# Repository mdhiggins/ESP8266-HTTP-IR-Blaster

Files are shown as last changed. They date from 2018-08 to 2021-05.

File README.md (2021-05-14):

# IR Controller

ESP8266 Compatible IR Blaster that accepts HTTP commands for use with services like Amazon's Alexa

<a href="https://youtu.be/JysKXOdrOlM">Setup</a>

The purpose of this project was to create a Wi-Fi enabled IR blaster that could be controlled with Amazon Alexa
This was designed with the NodeMCU board but should be compatible with multiple ESP8266 variants

Includes a functional web portal for code capture, output monitoring, and device state tracking

Device gives real time LED feedback, can handle complex code sequences for multi-device home theater control, and full integration with Amazon Alexa via the smart home entertainment devices API and the `IR Controller` Alexa skill

Hardware
--------------
Fancy
Breadboard Build
Schematic

The hardware is based on the NodeMCU ESP8266 board and uses an infrared LED combined with the 2N2222 transistor for increased current and range. Values of the resistors seen in the schematic are variable and will depend on the specifications of your LED. If you're using the LED recommended below then a 1000 ohm resister to the 2N2222 transistor and a 10 ohm resistor to the LED itself are appropriate values, otherwise please use an LED resistance calculator. In total the parts come in around $10 so building a controller for each IR enabled device in your home is very feasible, and most components are cheaper in bulk

Shopping List:
- [ESP8266 NodeMCU Board](https://www.amazon.com/gp/product/B01IK9GEQG/)
- [IR Receiver](https://www.amazon.com/gp/product/B00EFOQEUM/)
- [Super bright IR Led](https://www.amazon.com/gp/product/B00ULB0U44/)
- [2N2222 Transistor](https://www.amazon.com/gp/product/B00R1M3DA4/)
- [Resistors](https://www.amazon.com/gp/product/B00YX75O5M/)

*These are just quick Amazon references. Parts can be purchased cheaper with longer shipping times from places like AliExpress*

Drivers
--------------
Install the NodeMCU drivers for your respective operating system if they are not autodetected

https://www.silabs.com/products/development-tools/software/usb-to-uart-bridge-vcp-drivers

Alexa Skill
--------------
The companion skill for the Amazon Alexa service is available [here](https://www.amazon.com/Michael-Higgins-IR-Controller/dp/B0762YYDS9) for US/CA/UK/IN/DE Alexa customers

Setup
--------------

If you use [PlatformIO](https://platformio.org/), you can clone the repository and run `platformio run -t upload` to
compile the library and upload it to a connected ESP8266-compatible board.

Otherwise, here are the building steps:

1. Install [Arduino IDE](https://www.arduino.cc/en/main/software)
2. Install [ESP8266 Arduino Core](https://github.com/esp8266/Arduino)
3. Install the following libraries from the Arduino IDE [Library Manager](https://www.arduino.cc/en/Guide/Libraries): `ESP8266WebServer` `ESP8266WiFi` `ArduinoJson` `Time` `IRremoteESP8266` as well as [`Cryptosuite`](https://github.com/jjssoftware/Cryptosuite) and the developer version of [`WiFiManager`] which is now on the IDE (version >= 2.0)
4. Load the `IRController.ino` blueprint from this repository
5. Upload blueprint to your ESP8266 (the .ino file). Monitor via serial at 115200 baud rate

After flashing, you can use the device like so:

1. Device will boot into WiFi access point mode initially with SSID `IR Controller Configuration`, IP address `192.168.4.1`. Connect to this and configure your access point settings using WiFi Manager. If your router supports mDNS/Bonjour you can now access your device on your local network via the hostname you specified (`http://hostname.local:port/`), otherwise via its local IP address (this IP address is displayed on the serial output)
2. Forward whichever port your ESP8266 web server is running on so that it can be accessed from outside your local network, this is critical since Alexa commands come from Amazon's servers, not locally
3. Download the IR Controller Alexa skill and start creating your devices. Each IR command will require a URL which can be saved. Choose whichever functionality you desire. Information on creating the URLs can be found below

Alexa Setup
---------------
1. Download the `IR Controller` skill from the Alexa skill store
2. Login with your Amazon account
3. Go to https://tehpsyc.pythonanywhere.com/
4. Login with the same Amazon account you used for the skill login
5. Create a new device by specifying the friendlyName, endpointId, and description
6. Add whichever functionality you want your device to have by scrolling through the options on the page
7. Save your new device
8. Run device discovery on your echo device by saying "Alexa, discover devices" or via https://alexa.amazon.com/
9. Verify that your new device was discovered online or in the Alexa app and enjoy!

Server Info
---------------


You may access basic device information at `http://xxx.xxx.xxx.xxx:port/` (webroot)

Capturing Codes
---------------
Your last scanned code can be accessed via web at `http://xxx.xxx.xxx.xxx:port/` or via serial monitoring over USB at 115200 baud. Most codes will be recognized and displayed in the format `A90:SONY:12`. Make a note of the code displayed in the serial output as you will need it for your maker channel URL. If your code is not recognized scroll down the JSON section of this read me.

NodeMCU PCU
---------------
@raptordemon has created a PCB that works great with this project. Use version 1.5
https://easyeda.com/raptordemon/ESP8266_IR_blaster-f8f224faba554bf3bb6ce0e32759fc23

Basic Output
--------------
For sending simple commands such as a single button press, or a repeating sequence of the same button press, use the logic below. This is unchanged from version 1.
Parameters
- `pass` - password required to execute IR command sending
- `code` - IR code such as `A90:SONY:12`
- `address` - (optional) Additional address data for NEC codes. Hex format
- `pulse` - (optional) Repeat a signal rapidly. Default `1`
- `pdelay` - (optional) Delay between pulses in milliseconds. Default `100`
- `repeat` - (optional) Number of times to send the signal. Default `1`. Useful for emulating multiple button presses for functions like large volume adjustments or sleep timer
- `rdelay` - (optional) Delay between repeats in milliseconds. Default `1000`
- `out` - (optional) Set which IRsend present to transmit over. Default `1`. Choose between `1-4`. Corresponding output pins set in the blueprint. Useful for a single ESP8266 that needs multiple LEDs pointed in different directions to trigger different devices

Example:
`http://xxx.xxx.xxx.xxx:port/msg?code=A90:SONY:12&pass=yourpass`

JSON Scripting
--------------
For more complicated sequences of buttons, such a multiple button presses or sending RAW IR commands or Pronto commands, you may do an HTTP POST with a JSON object that contains an array of commands which the receiver will parse and transmit. Payload must be a JSON array of JSON objects. Password should still be specified as the URL parameter `pass`.

Please note that Pronto codes are often given in a hexadecimal format and need to be prefixed with `0x` to indicate as such or they will be incorrectly transmitted.

Parameters
- `data` - IR code data, may be simple HEX code such as `"A90"` or an array of int values when transmitting a RAW sequence
- `type` - Type of signal transmitted. Example `"SONY"`, `"RAW"`, `"Delay"` or `"Roomba"` (and many others)
- `length` - (conditional) Bit length, example `12`. *Parameter does not need to be specified for RAW or Roomba signals*
- `pulse` - (optional) Repeat a signal rapidly. Default `1`
- `pdelay` - (optional) Delay between pulses in milliseconds. Default `100`
- `repeat` - (optional) Number of times to send the signal. Default `1`. *Useful for emulating multiple button presses for functions like large volume adjustments or sleep timer*
- `rdelay` - (optional) Delay between repeats in milliseconds. Default `1000`
- `khz` - (conditional) Transmission frequency in kilohertz. Default `38`. *Only required when transmitting RAW signal*
- `address` - (optional) Additional address data used for NEC codes. Hex format
- `out` - (optional) Set which IRsend present to transmit over. Default `1`. Choose between `1-4`. Corresponding output pins set in the blueprint. Useful for a single ESP8266 that needs multiple LEDs pointed in different directions to trigger different devices.

3 Button Sequence Example JSON
```
[
    {
        "type":"nec",
        "data":"FF827D",
        "length":32,
        "repeat":3,
        "rdelay":800
    },
    {
        "type":"nec",
        "data":"FFA25D",
        "length":32,
        "repeat":3,
        "rdelay":800
    },
    {
        "type":"nec",
        "data":"FF12ED",
        "length":32,
        "rdelay": 1000
    }
]
```

Raw Example
```
[
    {
    "type":"raw",
    "data":[2450,600, 1300,600, 700,550, 1300,600, 700,550, 1300,550, 700,550, 700,600, 1300,600, 700,550, 700,550, 700,550, 700],
    "khz":38,
    "pulse":3
    }
]
```

Pronto Example
```
[
    {
    type:"pronto",
    data: [0x0000, 0x0069, 0x0007, 0x0000, 0x032a, 0x010e, 0x005a, 0x010e, 0x005a, 0x005a, 0x0168, 0x005a, 0x005a, 0x010e, 0x005a, 0x00b4, 0x005a, 0x01c2]
    }
]
```

JSON as URL
--------------
To send the signal using the IFTTT Maker channel or the IR Controller smart home skill, simply take your JSON payload and remove spaces and line breaks so that entire packet is on a single line, then added it to the URL using the `plain` argument.

Sample URL using the same 3 button JSON sequence as above
```
http://xxx.xxx.xxx.xxx:port/json?pass=yourpass&plain=[{"type":"nec","data":"FF827D","length":32,"repeat":3,"rdelay":800},{"type":"nec","data":"FFA25D","length":32,"repeat":3,"rdelay":800},{"type":"nec","data":"FF12ED","length":32,"rdelay":1000}]
```

Security
---------------
Due to limitations imposed by the hardware in the ESP8266, there is not enough free memory to communicate over HTTPS/SSL. To protect your devices, during the WiFiManager setup process you can specify your Amazon user_id which will act as a secret key that allows SHA256 HMAC authentication to take place. Without this time sensitive signature no codes will be sent from the device. The user_id is a unique identifier tied to your account and my developer account, not shared across any other Amazon services. This unique ID can be found at the bottom of the tehpsyc.pythonanywhere.com page. The format is `amzn1.account.xxx`, **NOT your account email**. Enabling this feature will prevent sending commands via other means but greatly increases the security of the device. By default the option `bypassLocalAuth` is set to `true` which will allow requests made to the device coming from your local network (based on your local IP address and subnet) to be processed without the HMAC authentication.

To send commands over SSL you can use an intermediate service such as Smartthings (see below), use a reverse proxy with HTTPS support (which should work with the native Alexa skill) such a nginx, or handle everything on the local network and not use the functionality with Alexa.

This article provides some details on using nginx
https://jjssoftware.github.io/secure-your-esp8266/

Multiple LED Setup
--------------
If you are setting up your ESP8266 IR Controller to handle multiple devices, for example in a home theater setup, and the IR receivers are in different directions, you may use the `out` parameter to transmit codes with different LEDs which can be arranged to face different directions. Simply wire additional LEDs to a different GPIO pin on the ESP8266 in a similar fashion to the default transmitting pin and set the corresponding pin to the `irsend1-4` objects created at the top of the blueprint. For example if you wired an additional LED to the GPIO0 pin and you wanted to send a signal via that LED instead of the primary, you would modify irsend2 in the blueprint to `IRsend irsend2(0)` corresponding to the GPIO pin. Then when sending your signal via the url simply add `&out=2` and the signal will be sent via irsend2 instead of the primary irsend1.

Default mapping
- irsend1: GPIO4
- irsend2: GPIO5
- irsend3: GPIO12
- irsend4: GPIO13
- irrecv: GPIO14
- config: GPIO10

Force WiFi Reconfiguration
---------------
Set GPIO10 to ground to force a WiFi configuration reset, this will boot the device into WiFi host mode with an SSID of 'IR Controller Configuration' and IP of `192.168.4.1`

Device State Memory
---------------
By adding the `device` and `state` parameters to your URL or JSON object, the device will remember the last sent state of the device. This is useful since Alexa has separate on and off commands, and without knowing the device state will end up turning the TV on if an off command is issued

Example Turn On URL (if TV was already turned on, this command will do nothing):
`http://xxx.xxx.xxx.xxx:port/msg?code=A90:SONY:12&pass=yourpass&device=tv&state=1`

Example Turn Off URL (if TV was already turned off, this command will do nothing):
`http://xxx.xxx.xxx.xxx:port/msg?code=A90:SONY:12&pass=yourpass&device=tv&state=0`

Minimal Output
---------------
For configuring URLs to work with IFTTT or the IR Controller skill, or other automation services where the HTML output of the device will never be seen by a human, add `&simple=1` to the URL to simplify the data sent and speed up the response time

Example:
`http://xxx.xxx.xxx.xxx:port/msg?code=A90:SONY:12&pass=yourpass&simple=1`

IFTTT
--------------
If you are unable to use the Alexa skill for whatever reason, or you are using a competing voice control product or some other implementation, then IFTTT can also be used to execute commands using the Maker channel HTTP commands. Simply generate your URLs and save them in the Maker channel

Smartthings
--------------
For a great write up and instructional on how to integrate this device with Smartthings please visit http://thingsthataresmart.wiki/index.php?title=How_to_Control_your_TV_through_Alexa_and_Smartthings

Thanks to @dham102

Roku
--------------
The Roku device supports sending commands via an API to simulate remote button presses over HTTP, but only allows connections via a local IP address. This blueprint supports sending these commands and acts as a bridge between IFTTT/Alexa to control the Roku with basic commands

Roku commands require 3 parameters that can be sent as a Simple URL or part of a JSON collection. Parameters include:
- `data` - [Roku code](https://sdkdocs.roku.com/display/sdkdoc/External+Control+Guide)
- `type` - Type of signal transmitted. Must be set to `roku`
- `ip` - Local IP address of your Roku device

Example Roku command to simulate pressing play button on a Roku with local IP `10.0.1.3`
```
http://xxx.xxx.xxx.xxx:port/msg?pass=yourpass&type=roku&data=keypress/play&ip=10.0.1.3
```

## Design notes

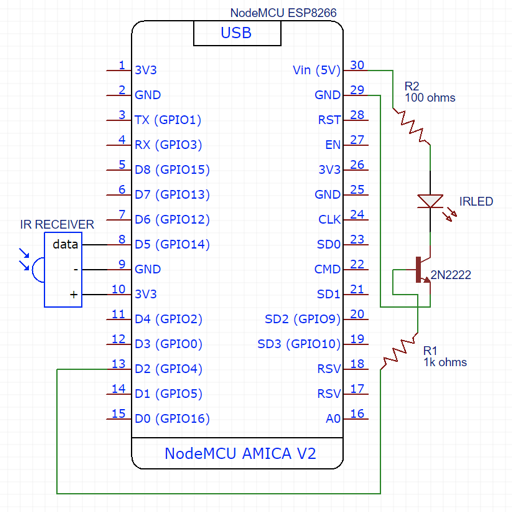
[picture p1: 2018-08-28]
512x512.png

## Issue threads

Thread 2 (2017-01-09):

Recalling IR Code issue

Fmkjr, 2017-01-09:
On firmware ESP Basic 3.0.Alpha 65, I have the ESP connected to the wireless at 10.0.0.220. It appears to receive IR codes and save them to locations, for testing I have "" all passwords. when I send 10.0.0.220/msg?code=1 from chrome it responds with "Triggering code 1"  not the IR code which is e0e09966:SAMSUNG:32 it seems to just respond with whatever I put after "code=" but doesn't error check or trigger an actual code or output to the IR.

[default.bas.txt](https://github.com/mdhiggins/ESP8266-HTTP-IR-Blaster/files/692610/default.bas.txt)

attached is the .bas I am using, for testing I have "" all passwords.
Thanks

mdhiggins, 2017-01-09:
What you're seeing as far as the HTML output is normal behavior.
I just pushed an update that will have the message say "Triggering" and then the IR code even when sending the saved codes (1-6), but the old behavior was just a messaging style choice, it shouldn't have impacted sending the code and does not indicate a problem.

If you're not getting IR output I would double check the wiring. The new update should help with debugged though to ensure the code has saved properly.

mmiscool, 2017-01-09:
The problem you are having is related to the esp basic firmware having not implemented support for sending samsung ir codes.

I noticed this issue and have compiled a new version of the esp basic firmware that has the samsung codes supported.

The new version is available at esp8266basic.com and should work. Version 3.0a65

Fmkjr, 2017-01-09:
Thank you, new code flashed sends codes. However the IR signal is very weak, I have to be with in 2ish feet for it to work.
Based on your diagram can I
1. Add 4 additional IR lads and wire them to in front of each device (example one in front of tv, receiver, etc)
or
2. Increase the output of the IR led some how.

I would like to place it about 8ish feet away if I can increase IR output

Thanks for responding so quickly.

mdhiggins, 2017-01-09:
Yes I actually used a 2N2222 transistor and connected my LED to the VIN pin of the ESP8266. This increases the voltage to 5V directly off the USB port and can draw much more current (compared to the tiny 12mA off the GPIO pins)

I'm at work but I'll post a diagram / pic of my latest revision of the board when I can.

Sent from my iPhone

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

mdhiggins, 2017-01-15:
See the V2 readme

Closed 2017-01-15.

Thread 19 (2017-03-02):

Roomba IR

Johnwulp, 2017-03-02:
Hi, i am using this sketch to get my Roomba start cleaning. In the wiki the code 136 should be the command to start cleaning. How do i call my ESP01 to send the right command? I tried `http://192.168.2.8/msg?pass=go&type=roomba&data=136` without succes.

mdhiggins, 2017-03-03:
Try

http://192.168.2.8/msg?code=136:ROOMBA&pass=go&pulse=3

Sent from my iPhone

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

Johnwulp, 2017-03-03:
Thanks, no success either. Going to grab another ir led and test again tonight

Johnwulp, 2017-03-03:
Well, left, right and forward action is working from my harmony one universal remote. Also the clean action doesnt work from here. Guess my roomba is somehow different. Using model 875. Thanks anyway!

ronnicek, 2017-08-03:
Hi, did you get it working somehow? :)

Johnwulp, 2017-08-03:
No, never got it working. Just pressing the clean button manually :-)

ronnicek, 2017-08-03:
I will let you know if I will get it working.. because pressing button is so 90'ish :D

ronnicek, 2017-08-03:
So following code is working with Roomba https://gist.github.com/ronnicek/28c2b004ee5f469ce264b1702ad19cc1 (I edit line 138 - but you can make diff from https://gist.github.com/madc/e6a06abaef28983d66bc to see what I changed :)

I have wemos d1 mini pro, with this LED (https://www.aliexpress.com/item/1pcs-Infrared-Emission-Module-IR-Transmitter-For-Arduino-Electronic-Blocks-new-Free-shipping/32655173182.html) but I have to have LED really, really close (have that on Roomba for testing). So I need to do some another way how to make LED more powerfull (I bought 10pcs 5mm IR Infrared LED 940nm Lamp Transmitting Tube Emitting Diode) so there is space for improvement :)

Try it and let me know :)

Johnwulp, 2017-08-03:
Thanks for your contribution! I have recycled my wemos d1. I will order another one, and some bright IR LEDs, and will try again.

ronnicek, 2017-08-09:
Hi,

so I had some time to play with that more.. and I find out, that Roomba after some time goes to something like "deep-sleep" mode.. because it do not react on power on signal.. I will try to figure out and let you know when I will have something :)

mdhiggins, 2017-08-09:
I have an old 500 series Roomba and have no issues. Can issues commands after days of inactivity without problems. Granted the only command I ever send is for it to start

My command looks like this, I did need pulse 3 to make it reliably turn on 100% of the time
`msg?code=136:ROOMBA&pulse=3`

ronnicek, 2017-08-09:
It's true that I didnt check this code, I just found this issue on search engine :) Can you share what electronics are you using (diode etc. ?).

I will try to upload this to Wemos and lets see if it will work :)

ronnicek, 2017-08-10:
So I found out this - http://imgur.com/a/1Ij7V :)

Johnwulp, 2017-08-18:
Well, I have a few fresh wemos d1 mini's And the good news is, that it is working. The problem on my side was that the code to start cleaning is 134 instead of 136.

ronnicek, 2017-08-19:
Great to hear! From how distance it works?

Johnwulp, 2017-08-19:
Well, I’m sending commands from 1 meter right now, with 1 5mm ir led. I don’t use a transistor, but I connected the led directly to the gpio port. I bought 50 leds for 2 dollar, so I have some spares 👍

shnax, 2017-08-19:
@ronnicek Did you figure out a way around that "deep sleep" issue? I'm running into the same thing with a roomba 652.

ronnicek, 2017-08-19:
@shnax nope.. but when Roomba is in dock, then you can start it with single signal (see http://imgur.com/a/1Ij7V)

raptordemon, 2017-08-29:
i can't for the life of me make this work, i have tried:

/msg?code=136:ROOMBA&pulse=3
/msg?code=136:ROOMBA&pulse=3&repeat=3&rdelay=250
/msg?code=134:ROOMBA&pulse=3
/msg?code=134:ROOMBA&pulse=3&repeat=3&rdelay=250
/msg?code=135:ROOMBA&pulse=3
/msg?code=135:ROOMBA&pulse=3&repeat=3&rdelay=250
/json?plain=[{'data':[2850,950, 950,2800, 950,2800, 950,2800, 2800,950, 950,2800, 950,2800, 950], 'type':'raw', 'khz':38, 'repeat' : 5}]

the last code was learned from my logitech harmony remote that was able to control the rooomba.

the only thing i can think of at this point is my IR led isn't the correct type for the roomba. it works with the TV

any ideas?

Johnwulp, 2017-08-29:
In using:

http://blaster.local/msg?code=136:ROOMBA&pass=GO&pulse=3

I have a password set, you don’t I guess from your url?

I have these ir leds. http://s.aliexpress.com/FfeMZZFz

raptordemon, 2017-10-04:
2 questions for you guys,
1) where are you aiming the IR led to get the roomba?

2) can someone share a link to some leds that are known working with the roomba?
thanks
Raptor

mdhiggins, 2017-10-05:
I'm using this one:
https://www.amazon.com/gp/product/B00ULB0U44/

And I point it from above right at the little circle at the front of the Roomba that's slightly elevated

raptordemon, 2017-10-08:
Hmm still doesn't work, moving on to checking the resistor values

mdhiggins, 2017-10-08:
What model roomba?

Sent from my iPhone

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

raptordemon, 2017-10-08:
its a 560 roomba, new resitors didnt work either

mdhiggins, 2017-10-08:
I’m using a 535 not sure if the remote codes are compatible or not. Far as I know they should be

Sent from my iPhone

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

raptordemon, 2017-10-09:
i expect that they are, it works when i use my logitech harmony 880 to control it, i even tried learning the codes and that didn't work either.... the esp8266 can control my TV.

honestly im at a loss

mdhiggins, 2017-10-09:
I was reviewing my Roomba power command and it looks like I had added `&pulse=3` and forgot to mention that. Now that I noticed I'm remembering that it wouldn't run without that pulse. I would try that and see if it helps, if 3 doesn't work just gradually increase and see (wouldn't go higher than 10)

mdhiggins, 2017-10-09:
The comments on this article have some other suggestions:
https://astrobeano.blogspot.com/2013/10/roomba-620-infrared-signals.html

Some people were changing the timings around from 3/1 to 3/1.1, others found that code 149 worked on some other models

Another thought is that its possible your docking station (which also uses an IR LED) is too bright and overwhelming the signal of your current LED, I would try sending the signal when its not near the docking station or with the docking station for testing purposes. That would make the most sense and would explain why the Harmony (which is a brighter device) still works. If that's the case then pushing the current or getting a couple IR LEDs to boost the signal might be worthwhile

The LEDs that I linked earlier that go up to 1A of current are a good option for really pushing the brightness

raptordemon, 2017-10-10:
can you elaborate on this: "Some people were changing the timings around from 3/1 to 3/1.1"
i tired the new codes and changing the pluses to 10 no luck :(

mdhiggins, 2017-10-10:
Did you try moving the Roomba away from its docking station or unplugging the docking station temporarily to see if helped?

And the timing codes are here: (line 1173/74)
```
  unsigned int one_pulse = 3000;
  unsigned int one_break = 1000;
```
People in the comments were changing the break to 1100 etc

joostwestra, 2019-04-12:
http://youserver.yourport/json?pass=yourpass&plain=[ { "type":"raw", "data":[2831, 886, 972, 2709, 944, 2711, 943, 2710, 2743, 893, 958, 2723, 931, 2722, 927, 19304, 2811, 897, 954, 2726, 927, 2726, 927, 2726, 2747, 889, 966, 2714, 942, 2710, 941], "khz":38, "pulse":3 } ]

While al the programmed Rooms commands with multiple repeats did not really work. Maybe the 19304 sleep time is critical.

Closed 2017-03-03.

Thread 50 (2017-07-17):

PCB for this hardware

raptordemon, 2017-07-17:
Hi,

thanks for building this, just wanted to let you know that i built a PCB for this code.

its not been tested yet but i will report back when its been tested:
https://easyeda.com/raptordemon/ESP8266_IR_blaster-f8f224faba554bf3bb6ce0e32759fc23

cheers!
Raptor

mdhiggins, 2017-07-19:
This looks really cool
I don't have much experience with this, is the 1.3 revision using the latest pin assignments now?
I'd definitely like to order a couple of these if you've tried
I thought I had replied to this comment earlier and may be going crazy but don't see that reply now
Let me know how it goes! Is this using the V2 nodeMCU?

mdhiggins, 2017-07-19:
Never mind it was on the pull request that I commented, sanity restored

But yeah definitely keep me posted and send some pics when you get the PCB ordered, I'd like to check it out

raptordemon, 2017-07-19:
yea sorry about that, feel free to delete one.

do these look correct?
int pinr1 = gpio14; // Receiving pin
int pins1 = gpio4; // Transmitting preset 1
int pins2 = gpio5; // Transmitting preset 2
int pins3 = gpio12; // Transmitting preset 3
int pins4 = gpio13; // Transmitting preset 4

its for the 25mm / 1in width node mcu like this one:
https://www.amazon.com/Generic-ESP8266-NodeMcu-Internet-Development/dp/B01N0B48NI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

im not sure if that counts as the v2

mdhiggins, 2017-07-20:
Yeah that's the V2, there's an unofficial V3 version that's larger that was made by some other company, that's why I asked

And those pinouts look correct yes

raptordemon, 2017-07-20:
great, i m going to reorder the boards this week and hopefully get it right this time.

mdhiggins, 2017-07-20:
One other question, it looks like the transmitters are using 3.5mm jacks? Maybe the receivers as well. What’s up with that?

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

Hasenpups, 2017-07-20:
Just as an information.
I use the firmware with this hardware: https://www.openhardware.io/view/385/MySWeMosIRShield-IR-blaster-shield-for-WeMos-D1

mdhiggins, 2017-07-20:
That's pretty cool looking, but looks like no spot for a receiver?

mdhiggins, 2017-07-20:
Nevermind, just saw the receiver

Hasenpups, 2017-07-20:
There is a receive on one side between two LEDs. Someone already printed a housing.

https://forum.fhem.de/index.php/topic,72950.msg659524.html#msg659524

mdhiggins, 2017-09-30:
Looks like the GPIO15 reset option was causing people a lot of problems, I had to change to GPIO10

Any chance I could get you to at least update the small blueprint? I'm not familiar with this and afraid I'm gonna screw something up

raptordemon, 2017-10-02:
sure no problem

mdhiggins, 2017-10-04:
GPIO10 is working well for me on the NodeMCU board, can't speak to the other variants but I changed all my boards over to that without problems

Also, I have a new update hopefully coming soon and am looking for a better tester that uses the IR Blaster with Alexa (and I guess is in the US cause of Amazon's limitations). Any interest?

kokarn, 2017-10-04:
Just ordered all the parts, this looks amazing. I'll be using it with IFTTT & Google Assistant, is that any help?

PS: The PCBs looks great as well, will get those as well ^^

raptordemon, 2017-10-04:
HI pcb's updated, v1.5 is the latest it has gpio10 as the wifi reset. i have not tested this board as i am using the v1.3 and still have boards.

please let me know if it works
Raptor

mdhiggins, 2017-10-05:
Awesome thanks, I'll order some for testing

Also @raptordemon if you use your devices with Alexa, any interest in beta testing something?

raptordemon, 2017-10-05:
yw.

yea i can do that.

mdhiggins, 2017-10-05:
Send me an email with your amazon account email address and I'll add you as a beta tester for a new skill

ipjcrane, 2017-10-05:
It’s ipjcrane@hotmail.com<mailto:ipjcrane@hotmail.com>

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

mdhiggins, 2017-10-05:
Invite sent, and sent you an email explaining the new features

mdhiggins, 2017-10-18:
@ipjcrane @raptordemon

Any luck with the beta testing?

If you need more help with setup here is a complete setup tutorial video that I finished making that will be live when Amazon enables the V3 API for all users
https://www.youtube.com/watch?v=JysKXOdrOlM

KDean7, 2017-10-24:
@raptordemon,
Are the circuit boards available yet?  Just starting this project and ordering parts now.  I have no breadboards and just heard about the samples you sent to mdhiggins.  Sounds like they'd be a much cleaner solution.

mdhiggins, 2017-10-25:
They are available. Use the v1.5 schematic when ordering. For first time builds though I would recommend using a breadboard for testing/debugging

w-brown, 2017-12-18:
Just wanted to say nice job!   I have built a prototype board using the ESP8266-12E module and am having fun playing with it.   I may decide to develop a board as well and share it out for those who want to reduce the size a bit as the NodeMCU is a bit bulky compared to the ESP module and a few surface mount components.

Do you have any plans to update the interface for the back end server?   One thing that would make it a bit more 'general user' friendly is if you had options not to have to enter the url for each command.  I feel if the interface simply asked for your ip, port, model of device, password, etc... and then for each command only required the hex codes for your remote it would make setting up various devices much simpler.

In any case, great job!

mdhiggins, 2017-12-18:
Probably not
While it would make the interface a little cleaner it locks in less flexibility and it would also potentially break compatibility with all the people who have already defined their devices
In the current iteration you can actually combine controlling different controllers within the same virtual device
That being said it would be nice to reduce some of the redundant data. I'll have to see if I can come up with a clever solution that's backward compatible

zobotek, 2017-12-21:
@raptordemon

0.  Nice job on the V1.5 PCBs!  Many thanks for sharing.

1.  I just ordered a batch of 10 large and 10 regular V1.5 boards from EasyEDA (China).  Got them and built them up today.  They were cheap - $26 got me 10 of each, including DHL shipping from China. Delivery was 3 days after ordering.

@raptordemon & @mdhiggins
2.  Only one problem:  configpin=GPIO10 crashed my NODEMCU board, even without being plugged in to the IR Blaster board.  Solution for me was to use configpin=16 (aka D0).  **It is NOT a good idea to use GPIO10 on a NODEMCU board because it's a reserved pin on some versions, including the NODEMCU Version 0.9 board which uses it for flash chip write control.**  0.9 NODEMCU crashes with pinmode(10,INPUT_PULLUP).

@raptordemon
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
RienduPre, 2020-01-05:
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

Did you ever got it to work? I have the same issue?

TheMCMan, 2020-01-05:
Hey there.  Got mine to work correctly.  I have a schematic that shows how to correctly determine proper part orientation.  Will post here later today.

Do you have pic of your esp board to place here?  Not sure what you mean by a 1.5 board big and small..

RienduPre, 2020-01-05:
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

TheMCMan, 2020-01-05:
Hey there, The PCB you posted a pic of is interesting.  It looks like all of the parts are positioned correctly.  Like the flat side of the LED and Transistor are placed correctly, which means the polarity is correct.  I traced the lines from the parts the best I could and everything appears to be good.

Please also send a pic of the ESP8266 board you plug into the headers on the PCB.  Maybe your ESP8266 has a different pinout than what is needed by the PCB.

Attached is a schematic I developed and used for this project based on the project notes:
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

Here is the PCB i built using this schematic:
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

If you use plug connectors, for like the LED, you would be able to swap out the parts more easily to see if you had a part that was malfunctioning.  I am currently transitioning to these connectors for my builds.
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

I then put my PCB into a project box.
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

please send a pic of your ESP8266 board

RienduPre, 2020-01-06:
Here you go.
The only difference I see is that I use a 180 ohm resistor and you 10 ohm

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

TheMCMan, 2020-01-07:
That's the exact same ESP8266 board I use : )

Believe you nailed it with your keen observation there lol.  Going from a 10 ohm to an 180 ohm resistor would have a great impact in my opinion.  This resistor size directly controls the brightness of the Infrared LED.

In the project video of IR Blaster Tutorial, at 1:32 minutes:seconds, mdhiggins references the resistance at 10 ohm as that would provide 500 mAmp current to the IR LED.

The IR Blaster Tutorial video is located here -- [https://youtu.be/JysKXOdrOlM](https://youtu.be/JysKXOdrOlM)

With a little experiment lol, maybe you can tell if you just have a rather dim IR LED bulb... find out exactly where the actual TV IR Receiver is located around the display screen.  What I normally do lol is put the remote like directly against the TV and move it around while pressing the on/off button.  When you identify that sweet spot that turns off the TV you can then hold your IRBlaster, with the IR LED pointed towards the TV of course, and send your commands away.

With any luck you will see that your device works but it's might be just a bit dim... then replacing the resistor will fix this.

I did see many diagrams on Google images showing a higher value resistor like you used.  When building mine I tried to just base it off of the video.  But every hurdle in this project seems to be monumental lol.

Out of the 4 boards I've built, I couldn't get 1 to work..  never figured out why, but I think it had a lot to do with my despicable soldering..

RienduPre, 2020-01-08:
I can't get it to work. I gave up and look for other methods to operate my fire place

benlye, 2020-01-08:
Just buy one of these.  Works really nicely with Michael's code.
https://www.aliexpress.com/item/32958748327.html

See #236 for more information.

mdhiggins, 2021-08-25:
@raptordemon not sure if you're still using this project or not, but was wondering if you'd be interested in making a small update to your PCB. I continue to use the 1.5 small version to this day and its been awesome

I'm looking to tweak the design a little in a coming update, removing 4th IR led and subsequent hardware and replacing it with an input using a optocoupler.

The goal is to allow a 5v input/ground from a USB cable to be connected to the optocoupler and then to use GPIO13 as an input pin. This would allow me to detect the TV state using power from the debug USB port present on most TVs for reliable state monitoring to prevent repeat "on" commands from turning a TV off when discrete codes are absent.

I currently have the external/debug USB 5v port with a 220 ohm resistor and external ground connected to one side of the optocoupler with GPIO13 connected on the other side.

The mqttdev branch is updated to include the code

I tried modifying your PCB design myself but realized I have no idea what I'm doing.

You would be able to eliminate one of  the 2N222 transistors and one resistor and repurpose the other resistor for the optocoupler

Here is a quick photo of my test setup

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

Thanks

mdhiggins, 2021-09-13:
Built a few of the boards and its working great! Thanks for the update

raptordemon, 2021-09-13:
thats great news! thanks for the feedback!!

________________________________
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

Closed 2020-04-24.

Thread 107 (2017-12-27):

More compatibility

glabbe0299, 2017-12-27:
Hi I managed to make it work so the Led is transmitting but however it doesn't seem to learn the code right as the code sent does nothing to my appliances.
My Tv is an LG and my receiver a Pioneer. Is there something I'm doing wrong ?

mdhiggins, 2017-12-28:
Need significantly more information

What codes are you trying to send?  How are you confirming that the LED is transmitting? What resistors are you using? How far away?

glabbe0299, 2017-12-28:
I’m Learning codes to turn off and on my Pioneer Amp and Lg tv. The led is transmitting as for the resistors I’m kind of a newbie and don’t really know what ohm to use. The leds are from an Ir blaster extension that came with a kit from a computer. I’m trying to send IR from 6 inch away or 2 feet no difference. Ir is coming out but it seems faster than the actual remote when seeing it from a phone camera.

Thanks for the help.

Provenance : Courrier pour Windows 10

De : Michael Higgins
Envoyé le :27 décembre 2017 22:47
À : mdhiggins/ESP8266-HTTP-IR-Blaster
Cc : glabbe0299; Author
Objet :Re: [mdhiggins/ESP8266-HTTP-IR-Blaster] More compatibility (#107)

Need significantly more information
What codes are you trying to send? How are you confirming that the LED is transmitting? What resistors are you using? How far away?
—
You are receiving this because you authored the thread.
Reply to this email directly, view it on GitHub, or mute the thread.

mdhiggins, 2017-12-28:
What commands are you sending?

glabbe0299, 2017-12-28:
I use the commands received by the software when I press the remote buttons aimed at the receiver. The module throws multiple results when I press on one button I don’t know if it’s normal.
As you can see when I press the power button for the amp at 23 :55 :25 I get 2 codes. Pressed it a second time and now one code 1 second later.

Provenance : Courrier pour Windows 10

De : Michael Higgins
Envoyé le :27 décembre 2017 22:52
À : mdhiggins/ESP8266-HTTP-IR-Blaster
Cc : glabbe0299; Author
Objet :Re: [mdhiggins/ESP8266-HTTP-IR-Blaster] More compatibility (#107)

What commands are you sending?
—
You are receiving this because you authored the thread.
Reply to this email directly, view it on GitHub, or mute the thread.

mdhiggins, 2017-12-28:
Can you post the codes and the URLs you're using to send them (you can strip out your IP address and pass)

And if you're getting 2 codes detected its probably a bad detection. There's noise and you often have to scan the code a couple times to get the right one

LG TVs usually use NEC encoding, not sure what Pioneer uses

mdhiggins, 2017-12-28:
In fact if its a newer LG there are hidden discrete on/off codes that don't toggle that are nice to use that I happen to know off hand
On: 20DF23DC:NEC:32
Off: 20DFA35C:NEC:32

glabbe0299, 2017-12-28:
http://xxx.xxx.xxx.xxx:xx/json?plain=[{'data':'A55AD02F','type':'NEC','length':32},{'data':'20DF10EF','type':'NEC','length':32},{'data':'FFFFFFFFFFFFFFFF','type':'NEC','length':0}]

Provenance : Courrier pour Windows 10

De : Michael Higgins
Envoyé le :27 décembre 2017 23:00
À : mdhiggins/ESP8266-HTTP-IR-Blaster
Cc : glabbe0299; Author
Objet :Re: [mdhiggins/ESP8266-HTTP-IR-Blaster] More compatibility (#107)

Can you post the codes and the URLs you're using to send them (you can strip out your IP address and pass)
And if you're getting 2 codes detected its probably a bad detection. There's noise and you often have to scan the code a couple times to get the right one
LG TVs usually use NEC encoding, not sure what Pioneer uses
—
You are receiving this because you authored the thread.
Reply to this email directly, view it on GitHub, or mute the thread.

mdhiggins, 2017-12-28:
The FFFFF command is basically a failed read command, you can strip that out as it won't do anything

The other 2 though look appropriate and are at least validly formatted codes and should work, so then I guess the question is do you have things wired up correctly. What ohm resistors are you using? and if you want, you can post a picture of your hardware and I can double check the wiring

glabbe0299, 2017-12-28:
I only have a 1K resistor from the 2n2222 to the board I did not have low enough resistor to put between the led and the board.
Everything fires up when asked I think I just have to experiment a bit more with Learning the codes.

Provenance : Courrier pour Windows 10

De : Michael Higgins
Envoyé le :27 décembre 2017 23:04
À : mdhiggins/ESP8266-HTTP-IR-Blaster
Cc : glabbe0299; Author
Objet :Re: [mdhiggins/ESP8266-HTTP-IR-Blaster] More compatibility (#107)

The FFFFF command is basically a failed read command, you can strip that out as it won't do anything
The other 2 though look appropriate and are at least validly formatted codes and should work, so then I guess the question is do you have things wired up correctly. What ohm resistors are you using? and if you want, you can post a picture of your hardware and I can double check the wiring
—
You are receiving this because you authored the thread.
Reply to this email directly, view it on GitHub, or mute the thread.

mdhiggins, 2017-12-28:
I would first try and get the codes to work individually then try grouped together

http://xxx.xxx.xxx.xxx:xx/msg?code=A55AD02F:NEC:32 for example and once you've confirmed that works then expand to the combo of the two

glabbe0299, 2017-12-28:
I will try to do that and confirm what I found.

Thank you

Provenance : Courrier pour Windows 10

De : Michael Higgins
Envoyé le :27 décembre 2017 23:09
À : mdhiggins/ESP8266-HTTP-IR-Blaster
Cc : glabbe0299; Author
Objet :Re: [mdhiggins/ESP8266-HTTP-IR-Blaster] More compatibility (#107)

I would first try and get the codes to work individually then try grouped together
http://xxx.xxx.xxx.xxx:xx/msg?code=A55AD02F:NEC:32 for example and once you've confirmed that works then expand to the combo of the two
—
You are receiving this because you authored the thread.
Reply to this email directly, view it on GitHub, or mute the thread.

mdhiggins, 2017-12-28:
If they work individually but not together you can try adding a delay between the two and see if its just trying to do them both too fast

kaotix, 2017-12-29:
I thought I'd jump in here. Having a similar issue as I also have an LG TV where I can get it to turn ON but not OFF.
I tried the codes mdhiggins suggested for OFF but that didn't work.
The code I get for ON/OFF button is 20DF10EF:NEC:32
My TV is LG 49UH603V

How much difference do the resistors and transistors have on the effectiveness of the IR LEDs?
I currently have my setup sat right in front of the TV and ON works flawlessly every single time.

glabbe0299, 2017-12-29:
I managed to make the Tv work when the IR led is 6 inch from the tv but the pioneer amp gives me trouble.
When I scan the Remote code with the ESP receiver i get 3 different raw codes. Not sure what to do with it.
I activated the HDMI control on the amp so when the tv goes off the amp shuts down too. I just hav to powerup the amp manually for the time.

mdhiggins, 2017-12-29:
@kaotix resistors can make a huge difference in range
@glabbe0299 the pioneer signal is a RAW command or 3 RAW commands pop up with each button press? Feel free to post those codes here; also what Pioneer receiver is it?

glabbe0299, 2017-12-29:
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
This is what it looks like when I press the power button one time.
It's a Pioneer VSX-921
I found the Hex code to power it up but can't manage to interchange with nec commands

mdhiggins, 2017-12-29:
That NEC command doesn't work to power up the device? It looks like it should
Because it gets sent at least twice, you could try adding a `pulse` parameter to your command and see if that makes it turn on, start with 2 and go up and see if it starts responding

mdhiggins, 2017-12-29:
Per the pioneer website these commands should work for that model:

Power On: `A55A58A7:NEC:32`
Power Off: `A55AD827:NEC:32`
Power Toggle: `A55A38C7:NEC:32` (consistent with the one you scanned)

mdhiggins, 2018-01-04:
Any updates?

glabbe0299, 2018-01-04:
I didn't had the time to try it and I will probably need an other Ir led to control the Amp as it is too far from the tv ir so I will probably test it this weekend. Thanks for the support.

jskubick, 2018-01-04:
Try explicitly specifying "khz" = "33". Pioneer has historically used NEC protocol, but with an oddball 33KHz carrier frequency.

mdhiggins, 2018-01-06:
You may need to send the signal as RAW if you're going to adjust the kHz though

mdhiggins, 2018-01-12:
Closing due to inactivity

Closed 2018-01-12.

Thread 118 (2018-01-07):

Panasonic TV not responding

MarkRiddoch, 2018-01-07:
I'm trying to get the IR Blaster to work with my Panasonic TV and DVR, but failing to get the TV to respond, has anybody managed to make this work?

The codes I learn from the remote for On and Off of the two devices are:
code=40040100BCBD:PANASONIC:48&address=0x4004   for the TV
and
code=40040D00BCB1:PANASONIC:48&address=0x4004   for the DVR

Alexa is talking to the Blaster fine and the codes the blaster web pages shows as being sent are the same as I expect. I have tried using pulse and pdelay (upto 20 or more times) but no response from the TV (the IR receive light never flickers).

I replaced the IR LED with a visible light LED (and resistor to bring the current down) and that flickered as expected - so I am pretty sure the electronics are fine. I've tried a couple of different IR LED's with r different resistors to match the current they could take. Also tried with less current, and a fresh LED, in case I had overdone it. I tried ranges from 2 inches to 2 to 3 feet. Nothing I try makes the TV or video respond.

Any suggests would be gratefully received
Thanks
Mark

mdhiggins, 2018-01-07:
https://github.com/mdhiggins/ESP8266-HTTP-IR-Blaster/issues/75

See if anything there is helpful regarding your codes

MarkRiddoch, 2018-01-08:
Thanks for getting back to me so quickly. I tried converting to use decimal, as indicated in the issue #75, but no change. I am beginning to suspect my IR LED's, so have order some of the Adafruit ones so that I know I have the same setup. Will try again when I get those.

mdhiggins, 2018-01-08:
Did you also try using the shorter codes that were listed there?
That person had some success removing the 40040 prefix from the codes (which seemed to be the address) and using the shorter version plus the address setting

MarkRiddoch, 2018-01-08:
Thank you, having read the issue I managed to somehow miss the bit about removing the 40040 prefix. Having done that things are working well, except for occasional failure to switch on. I think this is related to the number of times it needs to pulse the on command. I will play with this and hopefully make it more reliable.

Great project and thanks for the support.

mdhiggins, 2018-01-12:
Glad its working, gonna close for now

Closed 2018-01-12.

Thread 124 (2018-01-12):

WeMOS pinouts

mdhiggins, 2018-01-12:
The default pinouts do not work on certain WeMOS devices, most commonly the D1 Mini
The configpin in particular does not work

If we can crowd source a list of working pinouts I'll add an alternative blueprint option for WeMOS devices

WeMOS users please share what pin configuration you're using

jonathanhickford, 2018-02-02:
I'm using a WeMOS D1 Mini (v2.3.0). I've not tried using multiple IR receivers, but the below work for me.
```
const int pinr1 = D3;       // Receiving pin (Arduino GPIO0)
const int pins1 = D4;       // Transmitting preset 1 (GPIO2)
const int configpin = D2;   // Config pin (GPIO4)
```
In an ideal WeMOS world the config pin would perhaps be D3 (which is one used on the 1 button shield), but I had problems using that as the config pin.

vkhurana, 2018-02-04:
@jonathanhickford i tried this with my wemos, and it seems like the IR LED is always on? It only seems to go off when the wemos LED comes on. Can you share the circuit diagram you used? I'm using the one from readme, but adapted for Wemos D1.

jonathanhickford, 2018-02-07:
It was pretty much as the circuit diagram. I used the 5V output for the R2 -> IR LED -> collector.

lowtolerance, 2018-02-07:
D4 is what I used originally for transmission, and I couldn't figure out why it caused the LED to be so much dimmer than the same circuit hooked up to a NodeMCU on the same pin. Turns out that D4 is what the NodeMCU uses for it's onboard LED, and it already has a 10k resistor tied to that pin, so you end up with too much resistance on the line for full output.

D3 and D8 also have a 10k resistor, leaving D0-D2 + D5-D8 as the most sensible choices for IO.

jonathanhickford, 2018-02-08:
Thanks. I'm now trying the below, however like @vkhurana I'm finding the LED remains on all the time.
```
const int pinr1 = D5;        // Receiving pin (GPIO14)
const int pins1 = D6;        // Transmitting preset 1 (GPIO12)
const int configpin = D2;    // Reset Pin (GPIO4)
```

vkhurana, 2018-02-09:
@jonathanhickford maybe i have the same issue - you're using a 2N222?

jonathanhickford, 2018-02-09:
Yep 2N222 now - and the resistor values and LED as per the readme. That resolved my problem.

mdhiggins, 2018-02-09:
Are you guys just eliminating the configuration for S2-S4 or just leaving them at default and not using them? Gonna try and add this to the wiki page for future users

lowtolerance, 2018-02-11:
I’ve just been leaving the unused declarations at their default values. Might not be a bad idea to be able to enable/disable the additional transmitters through a simple Boolean, but it’s hardly necessary.

jebbett, 2018-03-18:
const int pinr1 = 14;                                         // Receiving pin (D5)
const int pins1 = 4;                                          // Transmitting preset 1 (D2)
const int configpin = 3;                                   // Reset Pin (RX)

I've got a couple of D1 Minis using the above config, shame there isn't somewhere for people to upload their projects.. The mini has a nice prototype shield that's idea for this and keeps it tiny, I have one with IR leds built in and one using a Samsung Smart TV IR Blaster BN96-31644A, which consists of 5 IR LEDs pointing each in different directions, all in parallel.. giving 360x180 degree coverage..

Closed 2020-04-24.

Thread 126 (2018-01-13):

Connect WiFi after few minutes shutdown (not respond)

kleusbalut, 2018-01-13:
i've encountered this issue.

connect to WiFi, after few minutes to shutdown (not respond, no wdt logs)

modules different shutdown time.
my tested modules case, 2-4 min or 30 min to shutdown.

[Environment]
Module: ESP-WROOM-02
Arduino-IDE: 1.6.13
ESP8266-Arduino-Core: 2.4.0
OS: Windows10 x64 FallCreatorsUpdate

I'm tried below.

[Hardware Side]
- tests other module, gets same issue.
- Add capacitor (470uF)
- Change power source

[Software Side]
- Upgrade ESP8266-Arduino-Core to newer version (2.4.0)
- Config pin change to GPIO12 (in ESP-WROOM-02, GPIO10 is used on board chip communication)

any idea?

best regards.

mdhiggins, 2018-01-13:
Can you post  the serial output for these connection failures?

There is a reset feature built in if it gets stuck in AP mode for too long to help prevent devices that reboot from a power outage from getting stuck in AP mode perhaps that is what's triggering things

kleusbalut, 2018-01-14:
thank you for replying.

i've got this issue, after WiFi Configured and STA mode connection.
and no Serial output logs. (silent death, no reboot)

[Additional Information]
- WiFi Manager Settings seems good work. done connect to my WiFi Network.
- Arduino IDE setting to Debug Port: Serial, Debug Level: CORE+WIFI+HTTP_UPDATE+UPDATER+OTA

mdhiggins, 2018-01-14:
Hm with no serial output I wonder if one of the pinouts is conflicting, that is usually the issue
I would try switching around the pins and run the device disconnected from all other hardware except USB and see if you can get serial output to work

Usually when you're getting crashes and no serial output its because one of the GPIOs that the device is using is reserved for a system function

mdhiggins, 2018-01-22:
Any updates?

Closed 2018-01-24.

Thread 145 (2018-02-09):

Sent command

eukiseioh, 2018-02-09:
Hi, i can scan codes and are displayed on server web when i want send the command via web “http://xxx.xxx.xxx.xxx:port/msg?code=A90:SONY:12&pass=yourpass” say “code sent ok” but don’t work. Any problem with led emitter?
what’s happen? i used 100 ohm to resistor....

mdhiggins, 2018-02-09:
Probably a hardware problem
Verify using an IR capable camera (most front facing cameras on cell phones) that your LED is lighting up when you issue a command

If not then double check all your wiring (feel free to post a picture of your build and I can take a look)

eukiseioh, 2018-02-09:
Ok i will send a pic and check wired and led polarity too...

eukiseioh, 2018-02-09:
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

eukiseioh, 2018-02-09:
monitor output:
Connection received - MSG
Blasting off
Blocking incoming IR signals
FFD02F:nec:32
Transmission complete
Reenabling receiving
Turning off the LED to save power.

Success! code sent... but don't happens anything

the address opcion field is "0X0" when i learn any code...

mdhiggins, 2018-02-09:
The address behavior is normal. Only Panasonic codes use that. Wiring looks good so I would check resistors and LED polarity. Use a camera to see if the LED is lighting up as well. If no light then you’ll need to check all your hardware for a bad component

eukiseioh, 2018-02-09:
Mmmmm  if the LED is not lighting up i will try another resistor (120 ohm for example). I think the led polarity is good. 5,5v —-> resistor 100 ohm —-> + LED (longest pin).

thommy6102, 2018-02-10:
It seem that you have the V3 Revision of the NodeMCU.
I have had the same problem, and I had roundabout 1V only on Pin 30  Vin. I`ve used Pin 18 VV instead.
I`ve meassured 5V on this pin, and it works for me since several days.

eukiseioh, 2018-02-10:
@thommy6102 Works Fine!! i changed to Pin VV
Thank you!

Closed 2018-02-11.

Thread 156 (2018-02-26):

Am I using the wrong board?

katamara, 2018-02-26:
I am having reboot issues (rst cause:4, boot mode:(3,6))

I am wondering if I may possibly be using the wrong board.

This is the board I am using:

https://www.aliexpress.com/item/NodeMcu-Lua-WIFI-Internet-of-Things-development-board-based-ESP8266-module/32668278518.html

IR Receiver:
https://www.aliexpress.com/item/10pcs-Lot-Universal-IR-Infrared-Receiver-Sensor-Module-1838-TL1838-VS1838B-38Khz-Diode/32507491875.html

2N222:
https://www.aliexpress.com/item/100pcs-free-shipping-2N2222-TO-92-40V-0-8A-NPN-switching-transistors-new-original/32506958631.html

IR LED:
https://www.aliexpress.com/item/50Pcs-5mm-940nm-IR-infrared-LED-Lamp/32224584146.html

mdhiggins, 2018-02-27:
Nope, that's the right board

The error you're getting is usually from having something connected to the wrong pin or having installed a library that wasn't meant for the ESP8266 (perhaps something for Arduino without ESP8266 support). Double check all your installed libraries and try booting the board without it being connected to anything except USB then slowly add back hardware

mdhiggins, 2018-03-03:
Any updates?

katamara, 2018-03-05:
I got rid of the reboot issues by changing the board in the Arduini IDE from NodeMCU v0.9 to NodeMCU v1.0

Closed 2018-03-05.

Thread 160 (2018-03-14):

Is there way to update Wifi Settings, without reseting ?

B0R1K, 2018-03-14:
Also is there way to safe External port, if you doing port forwarding...
lets say from from 8080 external to 80 internal...

Thank you,

jebbett, 2018-03-15:
What do you mean by resetting? The easiest option is to add a button or short the config pin to ground, do that as you press the reset button or add power..

For port forwarding, what you are saying is possible assuming your router supports it, but alternatively if your router doesn't then  just set the device port to something random.. I would probably pick something more cryptic than 8080 or 81 as both are frequently used.. but a bit of port sniffing would still discover the device.. I wouldn't call opening it up safe anyway, but relatively low risk..

Also if you have just added the ESP8266 board library, V1.4.1 has a memory leak and you will likely get issues, 1.4.0 works fine.. just to save you some headaches :)

B0R1K, 2018-03-16:
my point is that without saving external port somewhere in config, External URL get the wrong port...

Also i was asking if there a way to navigate to Wifi Config page without pressing a button, maybe there is hidden url or something... in case i what see what i entered... etc...

Thank you for Reply, i been playing with project and so far really like it...

jebbett, 2018-03-16:
The external port will be the same as the internal port if you just do a standard port forward, if you want to re-map this to something else externally on your router then you can.. when copying URLs from the web front end you can then just amend the :80 to :8080 or whatever you need..that's the easiest option here. It could be updated in code, but there are reasons to specify the internal port in the code as the web server needs to operate on that port, so it's mainly there for that purpose.. but the external port makes no difference other than displaying the link (I believe, I don't think this is used by Amazon?).. if you are keen to update the code you could do this by adding duplicates of the below fields thorough out the code with a prefix of ext then update the appropriate entries at about line 963 to refer to the extport instead of port

port
port_str

I had a play last night to see if I could get to the config page without pressing the button, I had no luck either.. it would be a good idea.. except that someone without physical access to the device could then in theory change the settings (a risk when you open to an external port).. This may be the reason it's not been opened, or could just be a code or memory limitation..

I've only been playing with this for a few months, and I now have a couple of these around the house linked to SmartThings.. I think this is an excellent project and quite simple even for a novice!

devax, 2018-03-18:
> Also if you have just added the ESP8266 board library, V1.4.1 has a memory leak and you will likely get issues, 1.4.0 works fine.. just to save you some headaches :)
Could you clarify which library you mean exactly? I checked all libraries mentioned in the README but could not find one with version number close to 1.4.0 / 1.4.1.

jebbett, 2018-03-18:
Yes sorry for the confusion!

Closed 2018-03-19.

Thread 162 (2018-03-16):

Force WiFi Reconfiguration not working

katamara, 2018-03-16:
The instructions say:
Force WiFi Reconfiguration
Set GPIO10 to ground to force a WiFi configuration reset, this will boot the device into WiFi host mode with an SSID of 'IRBlaster Configuration' and IP of 192.168.4.1

I have tried GPIO10 and also D7, and I wasnt able to get it to reset.  Probably because I am not sure exactly how to set a pin to ground.

I placed a jumper wire from GPIO10 (also tried D7) to one of the GND connections on the NodeMCU ESP8266 and plugged the usb power back into the device.  This didnt reset it.

How do I set one of the pins to ground?  Is this done while the unit is powered up or before it is powered and then you apply power?  How long do I leave it connected to ground?

mdhiggins, 2018-03-16:
You connect them to a ground volt source like you have described.
The state of the ground pin is printed during the boot sequence on Serial monitor I would start there and see what the reported state is
You need to have it set to ground during boot, after that point (once the boot sequence has completed) you can disconnect, though leaving it set to ground doesn't hurt anything until it resets again.

katamara, 2018-03-16:
Hmm, OK so that's what I was doing.  I'll go back and try again.  TY

katamara, 2018-03-16:
Thanks.  I just tried it again with GPIO10 and I was able to reconfigure it.

Not sure what I did wrong before, but it's working!  thank you

mdhiggins, 2018-03-17:
Good news everyone

Closed 2018-03-17.

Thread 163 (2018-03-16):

Assistance with lockup after boot?

chrislawson, 2018-03-16:
This is such a great project! Thank you for making it available.

I followed the steps in the readme to set everything up on a NodeMCU and did need to use the 1.4 instead of 2.0. I've configured wifi and It boots just fine after that however, it seems to freeze about 15 seconds after that. I have just enough time to open the root web page but it stops responding after that.

Can you offer any ideas one what I can check? Here is the output of the serial monitor with ext ip and pwd redacted.

ESP8266 IR Controller
Config pin GPIO10 set to: 1
mounted file system
reading config file
opened config file
{"hostname":"irblast","passcode":"****","port_str":"80","user_id":"","ip":"192.168.1.71","gw":"192.168.1.1","sn":"255.255.255.0"}
parsed json
*WM: Adding parameter
*WM: hostname
*WM: Adding parameter
*WM: passcode
*WM: Adding parameter
*WM: port_str
*WM: Adding parameter
*WM: user_id
Using Static IP
*WM:
*WM: AutoConnect
*WM: Connecting as wifi client...
*WM: Custom STA IP/GW/Subnet
*WM: 192.168.1.71
*WM: Using last saved values, should be faster
*WM: Connection result:
*WM: 3
*WM: IP Address:
*WM: 192.168.1.71
WiFi connected! User chose hostname 'irblast' passcode '******' and port '80'
WiFi configuration complete
Local IP: 192.168.1.71
URL to send commands: http://irblast.local:80
ArduinoOTA started
MDNS http service added. Hostname is set to irblast.local:80
HTTP Server started on port 80
External IP: xxx.xxx.xxx.xxx
External IP address request took 376 ms
Ready to send and receive IR signals
Turning off the LED to save power.
Connection received

mdhiggins, 2018-03-16:
Hm that’s a tough one it looks like everything is working as it should. What exactly freezes and after freezing does it crash or do you get any reports in the serial log or just what’s posted?

If you remove all connections from your board (disconnect from breadboard) and try again does that make any difference?

Sent from my iPhone

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

chrislawson, 2018-03-16:
Thanks for the quick response. I am currently testing with board only with nothing connected and no breadboard.

I am not sure how else to describe the 'freeze'. The board no longer responds to HTTP requests nor does it respond to IR signals when I had the receiver hooked up. Nothing else appears on the serial monitor after this point. The only way to get it to respond again is to press the reset button but then it just freezes again.

I tried another quick test by rebooting and then refreshing my browser as quickly as I could. I was able to get 3 requests in before it died. Here's all that is at the end of the log.

<SNIP>
Turning off the LED to save power.
Connection received
Connection received
Connection received

I am sure that the issue is related to my setup or something that I did, not necessarily a bug with your code. I'm a noob to this and was hoping for any guidance to help me troubleshoot and resolve.

FCustoms, 2018-03-17:
I have the same problemma, the receive-transmits about 5 times and freezes. only the reboot works.

mdhiggins, 2018-03-17:
Hm I have about 4 primary devices and multiple test devices and most of them have uptime measured in the months without rebooting. What hardware are you guys using that’s definitely not a standard issue

FCustoms, 2018-03-17:
I'm using LoLin's new NodeMcu V3 (serial ch340g). And the reset of the pins does not work, maybe this problem?
....I'll try to disable today the transfer serial, maybe can help.

mdhiggins, 2018-03-17:
Yeah I haven’t tested V3 all my boards are V2 so it might be a short on a pin. You can play around with the default pin outs and maybe try moving the receive and send pins around too. If you notice it fails after receiving a signal then maybe the receive pin is an issue and needs to be changed.

Sent from my iPhone

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

chrislawson, 2018-03-17:
I tried the full setup again from my mac instead win laptop and get the same results though, I was able to use the IwIP v2 instead of the v1. Upon boot the board responded for about a full minute then quit.

I am not sure what version my board is but I think at this point I need to order a new one and try again.

Feel free to close this. Thanks!!

devax, 2018-03-17:
Hey guys, I have a similar problem. I'm also using the so called "V3" variant of this board from LoLin. Everything seemed to work fine, but when I send multiple commands in a row, like pulse=3, the device will freeze and I will have to press RST button. By freeze I mean it will not respond to ping anymore and is not accessible. I have noticed, when I send a single IR command, the command gets executed, but one ping packet will be highly delayed (like 200ms compared to 3ms normally).
I wonder if it could be an "out of power" issue or something like that?
While assembling the board I found out that apparently you cannot use VIN with these boards; instead I used VV for 5V power supply.
The reason I hope to find a fix for that is because first tests looked good so I have just finished soldering everything together what took hours (guess I'm not too good in soldering) so it would be a pain to do it again with another board. Hope someone has a hint for me! Thanks!

devax, 2018-03-18:
I was able to resolve my freezing issues by downgrading the esp8266 board library in Arduino board manager from version 2.4.1 to version 2.4.0. This has been mentioned in issue #160 and this worked for me.

jebbett, 2018-03-18:
It’s a memory leak in lwip in 2.4.1, there is a bug raised in the project, hopefully fixed in 2.4.2, but as mentioned above 2.4.0 works fine..

FCustoms, 2018-03-19:
I confirm! changed version to 2.4.0 and it all worked

18 мар. 2018 г. 3:48 ПП пользователь "Jake" <notifications@github.com>
написал:

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

chrislawson, 2018-03-19:
I have had limited success with changing to 2.4.0.  I no longer experience freezes but only if I choose the the IwIP v2 Lower Memory or v2 Higher Bandwidth. Using v2 prevents retrieval of my external IP when I bring up web interface. It reports this message:

`Error - unable to retrieve external IP address, this is likely due to improper network settings`
`Error - EPOCH time is inappropraitely low, likely connection to external time server has failed, check your network settings`

If I use the IwIP v1.4 in combination with 2.4.0, I still get the lockup.

jebbett, 2018-03-19:
@chrislawson In 2.4.0 I don't get those options.. I only get the below, so may not be removed correctly?

- v2 Prebuilt (MSS=536)
- v2 Prebuilt (MSS=1460, unstable)
- v1.4 Prebuilt **<<< I'm using this**
- v1.4 Open Source

I'm not using external IP so can't add much more, although the guide does say to use lwip 1.4 as 2.0 causes issues.

chrislawson, 2018-03-19:
@jebbett you are correct. I looked at the list of boards and found there to be TWO ESP8266 Modules sections. I selected the correct board from the other list and found the v1.4 Prebuilt that was described.

Everything is now working exactly as expected. Very happy!

mdhiggins, 2018-03-19:
Glad its all working

Closed 2018-03-19.

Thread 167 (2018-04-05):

IR LED is not sending the signal

kiranreddyr, 2018-04-05:
i used the both the circuits i'm just receiving the signal but when i try to send the signal IR LED is not Blasting any signal      below i have attached the circuit connections i have made....
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

mdhiggins, 2018-04-05:
A little hard to tell from the pictures but it looks like everything is wired correctly. Make sure you don’t have your LED polarity reversed as that will prevent signal from being sent.

Next question is what command are you trying to send? Does everything else appear to be working without issue? No problems from the code? Post some logs of your attempts.

You can also check and see if the LED is lighting up using a camera without an IR filter (most cel phone front facing cameras).

Can also swap the LED with one from visible spectrum and see if it lights up

Sent from my iPhone

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

kiranreddyr, 2018-04-07:
i think the problem is with the code so can i get link for default.bas code

mdhiggins, 2018-04-07:
Default.bas is very old and works with none of the new features, does not work with Alexa
The problem is most certainly not with the code. The script and devices have hundreds of active daily users that aren't having issue. Its most likely a hardware issue. You can try connecting the LED directly to the data pin and eliminating the transistor
You can also try removing your resistor to the LED and see if that makes a difference
What resistors are you using? and have you confirmed you have the right ones?
You can also try taking a different LED (visible light, not IR) and see if anything is emitted

mdhiggins, 2018-04-07:
I guess I should also verify, what URL are you using to send the commands? Are you doing it through Alexa or browser? What remote code exactly are you sending? What does the website say when you send the command, is there an error? and finally post the serial output logs when you're attempting to send codes

kiranreddyr, 2018-04-09:
the code which i have to send is attached in the picture below....
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

To send the code i have to  press the Button or i have to go to browser and type this URL 192.168.4.1/msg?code=1

kiranreddyr, 2018-04-09:
If i hit this URL in Browser 192.168.4.1/msg?code=1   i'm just getting response as shown in below picture
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

mdhiggins, 2018-04-09:
Version 1 of the code is no longer supported
It uses a very old version of the IR Remote Library, has no security, and does not use Arduino
You should upgrade to the latest version

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

kiranreddyr, 2018-04-11:
so how can i upgrade to the latest version?is it by changing the code in Edit field to the the IRcontroller.ino code what u have given?

mdhiggins, 2018-04-11:
No, the ESP8266 boards actually support running the Arduino firmware and code

What you'll need to do is download and set up the Arduino IDE and go through the readme for the setup process for which dependencies you need. If you've never used Arduino or flashed a board I would look up some Youtube videos for people doing it with the NodeMCU. The .ino file is an Arduino file that you'll use to reflash the board

Once you get that working the Youtube video in the readme will be a good place to start

https://www.arduino.cc/en/Main/Software
https://youtu.be/JysKXOdrOlM

kiranreddyr, 2018-04-11:
i have already flashed NODEMCU so now is it possible to use the same board
or i have to use different board and do from first?

*Thanks & Regards*

*Kiran R*
*9036288730*

On Wed, Apr 11, 2018 at 10:11 AM, Michael Higgins <notifications@github.com>
wrote:

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

kiranreddyr, 2018-04-11:
HI Micheal,
is it possible for u to give some time so that we can have a chat...
You can say time when ever you are free so ill come online that time
pls i need your help Micheal..

*Thanks & Regards*

*Kiran R*
*9036288730*

On Wed, Apr 11, 2018 at 10:17 AM, kiranreddy r <kiranreddyr1993@gmail.com>
wrote:

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

kiranreddyr, 2018-04-11:
if its possible then we can share screen through Hangouts or Team Viewer

*Thanks & Regards*

*Kiran R*
*9036288730*

On Wed, Apr 11, 2018 at 10:40 AM, kiranreddy r <kiranreddyr1993@gmail.com>
wrote:

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
>>> No, the ESP8266 boards actually support running the Arduino firmware and
>>> code
>>>
>>> What you'll need to do is download and set up the Arduino IDE and go
>>> through the readme for the setup process for which dependencies you need.
>>> If you've never used Arduino or flashed a board I would look up some
>>> Youtube videos for people doing it with the NodeMCU. The .ino file is an
>>> Arduino file that you'll use to reflash the board
>>>
>>> Once you get that working the Youtube video in the readme will be a good
>>> place to start
>>>
>>> https://www.arduino.cc/en/Main/Software
>>> https://youtu.be/JysKXOdrOlM
>>>
>>> —
>>> You are receiving this because you authored the thread.
>>> Reply to this email directly, view it on GitHub
>>> <https://github.com/mdhiggins/ESP8266-HTTP-IR-Blaster/issues/167#issuecomment-380325037>,
>>> or mute the thread
>>> <https://github.com/notifications/unsubscribe-auth/AkVmAOh1QEcAASAEnD-4rhrQkPz3pD7Eks5tnYlhgaJpZM4TIUHe>
>>> .
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

mdhiggins, 2018-04-11:
Nah you can reflash as many times as you want

Sent from my iPhone

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

mdhiggins, 2018-04-11:
Sorry but I’m very busy and won’t have time to walk you through the process individually. I can answer specific questions they come up by email but that’s about the best I can do

Sent from my iPhone

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

kiranreddyr, 2018-04-12:
ok.. i already flashed that NODEMCU board and i'm able tho access IP address also

But now when i try to program it with Arduino IDE im not able get any COM port to program it....

i used NODEMCU flasher in beginning to flash this NODEMCU ESP8266

and now when i try to change the code version as u say im not getting any COM port

mdhiggins, 2018-04-12:
I can’t teach you the basics of using the Arduino software. There are thousands of projects and hundreds of YouTube videos that can walk you through it. This is not specific to my project this is a general Arduino question. Open source DIY projects require you to familiarize yourself with the background information before getting started

I will say there have been lots of bug fixes with the Panasonic codes in the later versions so you might have luck getting them working if you put the time in. I’m happy to try and field specific questions when you get further but you gotta put in the effort too.

Sent from my iPhone

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

Closed 2018-05-03.

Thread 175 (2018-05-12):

Device only stays joined to WiFi network for about 10 or 11 seconds

sdrasmussen, 2018-05-12:
Hi, all.  I am working my way through this project, and have hit a snag.  I can get the nodemcu to join my home WiFi network, and when it does, it answers ping and also web request.  However, it only stays joined to my WiFi network for about 10 or 11 seconds, after which it drops off, and will never join again, until I power cycle the device.  Is anyone else having this issue?

mdhiggins, 2018-05-12:
What version of lwIP are you using? and did you select the correct board? and what arduino ESP8266 version are you using?

Certain builds of ESP8266 and combinations with lwIP have memory leaks and cause networking problems

Also what hardware are you using?

sdrasmussen, 2018-05-12:
I am using 1.4 IwIP per your recommendation in the docs.  As for the arduino ESP8266 version, are you talking about my board?  If so, it is a nodemcu 1.0 with cp2102.  Not sure if I am answering your questions properly.  (extreme newb here)

mdhiggins, 2018-05-12:
Which build of the Arduino ESP8266 Core?
2.4.0 is the recommended one and later version have memory leaks

sdrasmussen, 2018-05-12:
2.4.1 is what I have installed.

mdhiggins, 2018-05-12:
Try rolling back to 2.4.0, 2.4.1 definitely is known to have a networking memory leak

Still make sure you use lwIP 1.4 prebuilt

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

sdrasmussen, 2018-05-12:
That did it!  You are the best, man.  Thanks a million for your time.  I can't wait to get this thing finished.  I 3D printed a case for it...should turn out looking pretty decent.

mdhiggins, 2018-05-12:
Feel free to share!
Glad its working

Closed 2018-05-12.

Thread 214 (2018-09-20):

Cannot connect to webserver after configuration

RienduPre, 2018-09-20:
Hi,

I can configure the wifi setup without a problem, but when it connects to my home wifi network I cannot open the IR management web interface, nor it can be pinged on the given ip adres.

However logging seems normal (see below)

ESP8266 IR Controller
Config pin GPIO10 set to: 1
mounted file system
*WM: Adding parameter
*WM: hostname
*WM: Adding parameter
*WM: passcode
*WM: Adding parameter
*WM: port_str
*WM: Adding parameter
*WM: user_id
Using Static IP
*WM:
*WM: AutoConnect
*WM: Connecting as wifi client...
*WM: Custom STA IP/GW/Subnet
*WM: 10.0.1.10
*WM: Using last saved values, should be faster
*WM: Connection result:
*WM: 0
Entered config mode
192.168.4.1
IR Controller Configuration
*WM:
*WM: Configuring access point...
*WM: IR Controller Configuration
*WM: AP IP address:
*WM: 192.168.4.1
*WM: HTTP server started
*WM: Request redirected to captive portal
*WM: Handle root
*WM: Request redirected to captive portal
*WM: Handle root
*WM: Request redirected to captive portal
*WM: Handle root
*WM: Scan done
*WM: DUP AP: Home2
*WM: Home2
*WM: -70
*WM: Sent config page
*WM: Request redirected to captive portal
*WM: Handle root
*WM: WiFi save
*WM: Parameter
*WM: hostname
*WM: IRBLASTER
*WM: Parameter
*WM: passcode
*WM: 12345678
*WM: Parameter
*WM: port_str
*WM: 80
*WM: Parameter
*WM: user_id
*WM:
*WM: static ip
*WM: 192.168.0.144
*WM: static gateway
*WM: 192.168.0.254
*WM: static netmask
*WM: 255.255.255.0
*WM: Sent wifi save page
*WM: Connecting to new AP
*WM: Connecting as wifi client...
*WM: Custom STA IP/GW/Subnet
*WM: 192.168.0.144
*WM: Already connected. Bailing out.
Should save config
WiFi connected! User chose hostname 'IRBLASTER' passcode '12345678' and port '80'
 config...
{"hostname":"IRBLASTER","passcode":"12345678","port_str":"80","user_id":"","ip":"192.168.0.144","gw":"192.168.0.254","sn":"255.255.255.0"}
Writing config file
Config written successfully
*WM: freeing allocated params!
WiFi configuration complete
Local IP: 192.168.0.144
URL to send commands: http://IRBLASTER.local:80
ArduinoOTA started
MDNS http service added. Hostname is set to IRBLASTER.local:80
HTTP Server started on port 80
Ready to send and receive IR signals
Turning off the LED to save power.

mdhiggins, 2018-10-01:
And you've got everything configured on the same subnet? Post your computer and router IP configurations as well as the URL you're trying

cap60552, 2018-10-04:
I am experiencing the same thing.
I can ping the ESP for a few seconds after a reboot/connect cycle and if i hit the webserver instantly after it boots and connects i can view the page, but it is only operational for a couple of seconds.   the whole device seems to crash at that point.

I did make sure to use the lwIP variant 1.4, but it didn't seem to make a difference.  I also tried 2 different devices, a standard nodeMCU 1.0 device, and a wemos v1 device.  Both experienced the same problem.

Sawoff, 2018-10-04:
I've the same problem here

cap60552, 2018-10-04:
I missed that bug. I'll try downgrading the board library tonight when I get home.

jonsel087, 2018-10-09:
Hi all, really hoping someone can help me debug. I am unable to connect to the webserver, even after downgrading to ESP8266 2.4.0 and using "IwIP variant Prebuilt". The serial plotter reads:
```
ESP8266 IR Controller
Config pin GPIO10 set to: 1
mounted file system
*WM: Adding parameter
*WM: hostname
*WM: Adding parameter
*WM: passcode
*WM: Adding parameter
*WM: port_str
*WM: Adding parameter
*WM: user_id
Using Static IP
*WM:
*WM: AutoConnect
*WM: Connecting as wifi client...
*WM: Custom STA IP/GW/Subnet
*WM: 10.0.1.10
*WM: Using last saved values, should be faster
*WM: Connection result:
*WM: 3
*WM: IP Address:
*WM: 10.0.1.10
WiFi connected! User chose hostname 'IRBLASTER' passcode '2345' and port '80'
*WM: freeing allocated params!
WiFi configuration complete
Local IP: 10.0.1.10
URL to send commands: http://IRBLASTER.local:80
ArduinoOTA started
MDNS http service added. Hostname is set to IRBLASTER.local:80
HTTP Server started on port 80
Turning off the LED to save power.
Error retrieving external IP
HTTP Code: -1
connection refused
External IP address request took 5002 ms
Ready to send and receive IR signals
Signal received:
One line: FFFFFFFFFFFFFFFF:NEC:0 (Repeat)
uint16_t  rawData[3] = {8864,2360, 520};  // NEC FFFFFFFFFFFFFFFF
uint64_t  data = 0xFFFFFFFFFFFFFFFF;
Turning off the LED to save power.
```

From what i see the issue is that it's not setting the default IP to my subnet. Any ideas? Thanks in advance!

cap60552, 2018-10-09:
One thing you could try is to turn off the static up and use DHCP.  Just try commenting out :
wifiManager.setSTAStaticIPConfig(sip, sgw, ssn);

And wifiManager will default to DHCP.    Then you can make sure everything is still running and hasn't crashed.

jonsel087, 2018-10-10:
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

Cap, thank you so much! That indeed got it working. I was able to get the local server running and configure the device. It's showing up on my Alexa app, unfortunately when I try to issue a command to Alexa it says the device is not responding. If I open up the device on the app, it just shows device info, not the Power On/Off functionality i added. Any idea if that's normal?

mdhiggins, 2018-10-10:
That’s normal. Did you forward your ports and are able to view the device from your external IP? And if DHCP is working then I would guess you didn’t configure your static network settings correctly

Sent from my iPhone

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

skorokithakis, 2018-10-10:
Why is it defaulting to static, though? DHCP is the better default for the vast majority of users.

skorokithakis, 2018-10-10:
I'm afraid this is happening to me with DHCP as well. It seems like the ESP is disassociating from the WiFi access point, as I can no longer see it in the list of devices on the router after a few seconds. I don't know why this might be, though...

skorokithakis, 2018-10-10:
Even with LwIP 1.4, I am experiencing crashes. Does anyone have a working build they can upload somewhere?

jonsel087, 2018-10-11:
I'm not able to connect to the esp8266 with port forwarding turned on (am trying to connect to external IP from my cell phone, not sure if that's right. will need to find some documentation). When connecting locally, getting unresponsive pages/poor performance. Additionally, seeing these logs in my router:
```
Wed Oct 10 22:18:01 2018 | Critical (3) | SYNC Timing Synchronization failure - Failed to acquire QAM/...
Wed Oct 10 22:18:03 2018 | Warning (5) | MDD message timeout;CM-MAC=00:40:36:4b:f7:40;CMTS-MAC=00:01:...
```

mdhiggins, 2018-10-11:
DHCP isn't the default because its a static device with port forwarding, using DHCP doesn't make sense as any time DHCP reassigns IP address your port forwarding settings will fail

Post your full Arduino build settings (should be displayed at the status bar at the bottom of your IDE), and post all your router IP address settings (IP, subnet) and post the static settings you were trying to assign.

Only thing you don't need to post is your external IP address, and I wouldn't advise that.

mdhiggins, 2018-10-11:
Also, are there any special networking circumstances? Like are you behind a double NAT for instance?
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
mdhiggins, 2018-10-11:
Also looking at the build flags and I see PIO_FRAMEWORK_ARDUINO_LWIP_HIGHER_BANDWIDTH
Not 100% sure if that is equivalent to lwIP v1.4 prebuilt that's included with the nodemcuv2 board option that Arduino IDE uses (the high bandwidth and low bandwidth variants are not options when you switch to the correct board) but looking at the PIO documentation I don't see any additional build flags

mdhiggins, 2018-10-11:
d581294747eee5a7dbef4ed8ff2227a420dd9a79

May need to mess with the lwIP variant still but give that a try

skorokithakis, 2018-10-11:
My problem seems to have been with my router, I realized this when my ESPs started disconnecting one by one. In my case I set my router's encryption to TKIP/AES and everything was fixed. Ignore me, PlatformIO builds work fine.

jonsel087, 2018-10-12:
> DHCP isn't the default because its a static device with port forwarding, using DHCP doesn't make sense as any time DHCP reassigns IP address your port forwarding settings will fail
>
> Post your full Arduino build settings (should be displayed at the status bar at the bottom of your IDE), and post all your router IP address settings (IP, subnet) and post the static settings you were trying to assign.

Hi Mike,
Thanks for the support, really hoping to get this working! Noted about DHCP, I will switch to static once i get it running (for some reason can't retrieve external IP when using static). I've double checked the IPs for now to make sure they haven't changed.
* Here's my build settings: `NodeMCU 1.0 (ESP-12E Module), 80MHz, 4M (1M SPIFFS), v1.4 Prebuilt, Disabled, Non, 115200 on Com4`
* Chip Model: `ESP8266MOD`
* Gateway: 192.168.0.1
* ESP ip: 192.168.0.19:80
* i have set up port forwarding and specified the external/internal IP addresses and the correct port. There is also a DMZ function i turned on for the local IP which bypasses firewall

I ran through the process again, this time specifying my amazon  user id in the `user_id` field. I updated the passcode and edited the request url but getting the same result. (i left hostname at default, i'm unable to connect using mdns anyways so using local ip).

This time I'm getting a new message from the serial plotter:
```
Epoch time from timeServer is unexpectedly old, probably failed connection to the time server. Check your network settings
37
Invalid EPOCH time, security checks may fail if unable to sync with NTP server
```

Dumb question, but could you please confirm which of the urls from captured signal to specify? (i.e, external, hostname, local) I'm assuming external is correct, but what are the others for?

mdhiggins, 2018-10-12:
I wouldn't use both port forwarding and DMZ, just do port forwarding as you are opening up way more ports than you need to use DMZ

I assume your router's local IP address is also 192.168.0.1 and you can access the ESP8266's web portal

Your build settings all look correct, but its still failing to get the EPOCH time. EPOCH time is unix time, which should be a large number (can see the current unix time here https://www.epochconverter.com/)

Sometimes I've seen it fail due to strange DNS setups where the router didn't support DNS hosting, a limitation to WiFiManager's static IP address settings. Was the EPOCH time giving you an error and small number when you did the settings via DHCP?

One thing you can try to take DNS out of the equation is to modify the blueprint and change line 71 from
`const char* poolServerName = "time.google.com";` to `const char* poolServerName = "216.239.35.0";`
This is the direct IP to time.google.com so you don't depend on DNS and see if that fetches the appropriate EPOCH time

mdhiggins, 2018-10-12:
And yes, Alexa needs to be pointing to the external IP address since the commands from the skill come from Amazon's servers outside of your local network, and you should be able to access your device's status page from your external IP address

cap60552, 2018-10-12:
I use DHCP to assign a static ip. Recently I added a secured iot vlan and
was able to shift all of my IR blasters to the new subnet and had
everything up and running on the new subnet in a matter of minutes without
having to recompile or try to get OTA to work.  This is especially nice in
the case of the blasters I have embedded in waterproof boxes mounted
outside used for controlling cheap floodlights.

On Fri, Oct 12, 2018, 6:49 AM Michael Higgins <notifications@github.com>
wrote:

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

Closed 2018-10-20.

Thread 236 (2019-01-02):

Geeklink IR Blaster - Cheap

arduino43, 2019-01-02:
I just reprogrammed one of these IR Blasters from AliExpress with ESP8266-HTTP-IR-Blaster. For anyone looking for a complete solution that will work with this code these are a great.

https://www.aliexpress.com/item/New-Geeklink-Smart-Home-WIFI-IR-4G-Universal-Intelligent-Remote-Controller-For-iOS-Android-Compatible-with/32958748327.html

Inside the unit is an ESP-12F with headers you can use to connect with either an Arduino or a USB-to-Serial adapter.

mdhiggins, 2019-01-03:
That's pretty cool, thanks for sharing

kaypohl, 2019-01-08:
Could you please share some pictures from the inside of the unit? And is there anything to change or only to flash the HTTP-IR-Blaster Firmware?

Kay

arduino43, 2019-01-08:
https://ibb.co/341KV5Y

No need to modify anything.

How I did it:
USB to Serial (5v)

5v to board 5v pin
RX to board TX
TX to board RX
GND to board GND

Also note that you will need to place a jumper from the KEY to GND to put the ESP into flash mode when uploading.

Pin 5 is the IR Receiver
Pin 14 is the IR Transmitter(s)
Pin 12 is the red status LED on the front of the unit
Pin 13 is the orange L:ED on the front of the unit

mdhiggins, 2019-01-08:
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

Like  this? Not seeing where the 5v pin should connect on this image though

arduino43, 2019-01-08:
Like this....

https://ibb.co/smpnfZF

mdhiggins, 2019-01-08:
Ah gotcha, the existing micro USB port on there isn't usable?
Gonna order one today and mess around

arduino43, 2019-01-08:
Not for programming the board, only for powering the device.

benlye, 2019-01-08:
Ordered one as well :-)

benlye, 2019-01-08:
Adding the USB<->Serial wiring here for in-line reference:
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

kaypohl, 2019-01-08:
Ordered 2 :-) Thanks for sharing this information.

benlye, 2019-01-18:
Received mine today.  Wired it up and was eventually able to flash it.

Tip that might save others some head-scratching - the mini USB cable that comes with it is NOT a data cable, so don't bother trying to use it with your CH340G!

arduino43, 2019-01-18:
Yeah I did mention that.

Sent from my iPhone

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

arduino43, 2019-01-18:
Ah ok yeah. I actually also ran into issues where other USB cables wouldn’t power the device.

Wondering if the cable supplied has nonstandard wiring.

Sent from my iPhone

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

benlye, 2019-01-18:
> Wondering if the cable supplied has nonstandard wiring.

Certainly seems that way - mine only wants to power on with the supplied cable too.

arduino43, 2019-01-18:
Also, I found that the device would be come unresponsive at times.

I started using the MQTT branch and it worked much better.

Sent from my iPhone

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

benlye, 2019-01-18:
> Also, I found that the device would be come unresponsive at times. I started using the MQTT branch and it worked much better.

Good to know - I'll keep an eye on it.

mdhiggins, 2019-01-18:
MQTT branch? Link?

And the unresponsive stuff is probably a wifimanager issue make sure you’re using lwIP v1.4 and ESP8266 Core 2.4.0

Sent from my iPhone

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

arduino43, 2019-01-18:
I compiled it with 1.4 prebuilt but it would become unresponsive after 1-2 hours for some reason.

Sent from my iPhone

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

kaypohl, 2019-01-20:
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

Can you please tell me more about the MQTT Branch?

Kay

arduino43, 2019-01-24:
If you have a multimeter you can easily find out - just follow the trace to the pin chip.

You could also upload a simple push button sketch using different pins and check when the pin is pulled high when pressed.

kaypohl, 2019-01-24:
I have a multimeter. But I can't follow the trace. I will try the option with the button sketch.

kaypohl, 2019-01-24:
@arduino43 do you still have problems that the device becomes unresponsive?

mdhiggins, 2019-01-24:
Just got my device and USB adapter so I'll be trying this out tomorrow. Keep me posted on any discoveries

kaypohl, 2019-01-24:
@arduino43 @mdhiggins  I've got the same problem. The device becomes unresponsive after a while. Mostly after sending commands with normal remote to my TV. When I check the webserver there are some weird readings from the IR receiver. Also the LED flashes without sending or receiving. Really strange.

arduino43, 2019-01-24:
Use pull request that added MQTT. I use MQTT but it also doesn’t crash using HTTP either.

kaypohl, 2019-01-25:
@arduino43 But you wrote that your device becomes also unresponsive after a time. What did you do that your device stay responsive either with Http?

arduino43, 2019-01-25:
It does not using MQTT pull

kaypohl, 2019-01-25:
Yes ok. But do you use still http without problems?

arduino43, 2019-01-25:
Yes

kaypohl, 2019-01-26:
> Yes

And what did you changed? You wrote that you had problems, and now your are still using http without problems?

Kay

kaypohl, 2019-01-27:
@mdhiggins I think the "freez" of the esp12 has to do with the ir receiver. After I've done this:

//irrecv.enableIRIn();

there was no freeze anymore. Of course I am not able to receive new codes.

Kay

benlye, 2019-01-28:
Mine is doing the same - dying after a random amount of time, less time if there is a lot of use of the actual remotes.

Don't know what others devices are doing, but mine always dies with the red LED on, which makes me wonder if it's something in the `loop()` that is going wrong.

kaypohl, 2019-01-29:
> Mine is doing the same - dying after a random amount of time, less time if there is a lot of use of the actual remotes.
>
> Don't know what others devices are doing, but mine always dies with the red LED on, which makes me wonder if it's something in the `loop()` that is going wrong.

Mine is also dying with red led on. As a workaround I disabled the receiving of ir signals. Since then the device stays available.

benlye, 2019-01-30:
I seemed to get better stability by commenting out most of the lines which handle receiving IR transmissions in the `loop()` function - basically making it so that all that happens when another remote is used is the blaster's LED flashes.

I'm going to work through re-enabling each line to see if the stability problem comes back.

CodeFinder2, 2019-01-30:
Any tips on opening the device? Don't want to damage it... 🙈

kaypohl, 2019-01-31:
> I use the MQTT version and it never goes offline unexpectedly

Where can I find this MQTT version?

arduino43, 2019-01-31:
https://github.com/mdhiggins/ESP8266-HTTP-IR-Blaster/pull/197

benlye, 2019-01-31:
FYI, S1 pulls GPIO16 (the flash pin) low, so can be used to put the board into upload mode.

mdhiggins, 2019-02-01:
Please share

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

benlye, 2019-02-01:
Here you go:
https://github.com/benlye/ESP8266-HTTP-IR-Blaster/tree/geeklink-config-button

I've found it's sometimes necessary to do an additional power cycle if the button isn't released quickly enough.

Regarding the stability, my device seems better with these two lines commented: https://github.com/mdhiggins/ESP8266-HTTP-IR-Blaster/blob/master/src/IRController.ino#L1626-L1627

Need a bit more runtime to be conclusive, then I'll try to work out why.  I've looked at the MQTT PR and I don't see anything jumping out as to why that might behave differently.

CodeFinder2, 2019-03-03:
Has anyone verified that pin 14 actually uses **all** 7 IR LEDs on the board for sending?
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
stritti, 2019-04-15:
I just received a new - unchanged device: I checked, there all IR LEDs are used. Just to let you know.

CodeFinder2, 2019-04-15:
> I just received a new - unchanged device: I checked, there all IR LEDs are used. Just to let you know.

Thank you very much! :-) Would you mind extracting (and uploading) the original firmware from the device using (see, e. g., [here](https://github.com/arendst/Sonoff-Tasmota/wiki/Esptool#optional-backup-firmware)):
```esptool.py --port COM5 read_flash 0x00000 0x100000 image1M.bin```

whereby "COM5" is the appropriate serial port. I would like to test it on my device to see if it's software related. Thank you very much again!

stritti, 2019-04-15:
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

I'll try. First of all I have to add connections wires :)

CodeFinder2, 2019-04-15:
Thank you so much! If you need help, just let me know. ;-)

stritti, 2019-04-15:
shit, I think I killed the 5V-Pin on the device. Is here a way to connect somewhere else?  The SONOFF S20 is quite easier to modify :/

CodeFinder2, 2019-04-15:
:-(

Can you show me a picture of how your board looks like right now? I am not having the board at hand (I can take a look in the evening today when I am back home) but maybe there's another 5V pad/pin on the bottom of board (?).

stritti, 2019-04-15:
That was also my first try, but there is nothing on the downside.
It looks like following, but the 5V pad isn't there any more:
https://user-images.githubusercontent.com/23322579/50835547-de54ff80-134e-11e9-97f9-2bcf8051dbc5.jpg

CodeFinder2, 2019-04-15:
Puh, not good. I just had a look at the bottom and yes, there's nothing like that. Hm. If you have a soldering iron, you can try to add solder to the location where the pad was previously but I am also not sure if it will adhere there.

I have another idea but honestly, I don't know if that works or if it even destroys the board/ESP completely: you can use an old micro USB cable, cut the cable, strip the isolation and identify the 5V and GND wires (advisable to use a multi meter, just to be sure). Then you take your USB-to-serial adapter and connect 5V and GND to the 5V and GND wires of the cut USB cable respectively. Plug the cut micro USB cable into the board. Finally, you just need to solder a pin header to the TX, RX and GND holes on the board in order to connect them to your USB-to-serial adapter as well. Make sure that the GND pin (next to the RX/TX pins), the GND pin of your USB-to-serial adapter as well as the GND wire of your cut USB cable are all connected (same ground). After that, connect the USB-to-serial adapter to your PC.

Note that you can enter flash mode of the ESP either by shorting KEY and GND (e. g., with a jumper if you added an appropriate pin header like I did in my photo) or by keeping the button "S1" pressed during boot/power up. ;-)

But again, I don't know if that will actually work. If you try it, please don't forget to extract the original firmware.

Hope that is clear. :-)

2016for, 2019-05-06:
This is amazing! Do you know of any other devices that can be flashed?

Like Broadlink RM mini 3, or those Tuya thingies?

arduino43, 2019-05-20:
Judging by the pictures you could flash this device.

Just follow the wiring diagram for the GeekLink IR Blaster, its basically the same process (put the board into programming mode and flash the updated firmware)

CodeFinder2, 2019-05-27:
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

Just for those who are interested: I can now confirm that my IR LEDs were broken (3 out of 7) and since they are controlled in series (2 in a row, except for the middle LED), all LEDs on the "outer ring" were off. I soldered new IR LEDs and now all work fine. Chinese quality ...

cnsellon, 2020-01-16:
bringing this discussion back up:

I ordered a new GeekLink from AliExpress last week and it came in. Seems they have updated the design to V104 (images shared of v102) and they have removed any of the TX RX and Key pads/pins to the right of the ESP-12L. Is it possible to leverage the pads to the left side of the ESP?

If that's the case and KEY has also been removed, would it be possible to still flash the device with SW1?

Thanks for any help.

CS

frankhommers, 2021-06-23:
> I ordered a new GeekLink from AliExpress last week and it came in. Seems they have updated the design to V104 (images shared of v102) and they have removed any of the TX RX and Key pads/pins to the right of the ESP-12L. Is it possible to leverage the pads to the left side of the ESP?

Did you already manage to flash it? I am wondering the same thing....

mojrs10, 2021-07-20:
I think i have "incomplet" Geeklink GK01...I cannot recive signal from any remote.
In first pictur I thin IR reciver is soldered on H1 but on my board this is empty.

Closed 2020-04-24.

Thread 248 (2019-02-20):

Compatible Device "Orvibo CT10W"

HerrPausL, 2019-02-20:
Hello,
just a short Info about a compatible device.

This device is using the ESP8266 and looks realy nice: https://www.orvibo.com/en/product/xiaofang.html

The PIN-Out is:
//  0 = fw update
//  2 = ?
//  4 = button (input)
//  5 = IR Rx (input)
// 12 = blue LED (output)
// 13 = ?
// 14 = IR Tx (output)
// 15 = red LED (output)

Picture of PCB:
http://bplagens.bplaced.net/ESP8266/Top.PNG
http://bplagens.bplaced.net/ESP8266/Bottom.PNG

My ArduinoIDE settings:
http://bplagens.bplaced.net/ESP8266/ArduinoIDE.PNG

At Aliexpress the price is aprox 16€.
At Amazon i payed ~30€

BR Bernd

CodeFinder2, 2019-04-25:
How did you open the device?

HerrPausL, 2019-04-26:
Hi,

after work i will made a picture for you how i did the job.
But basicly just a knife and soft-force.

BR Bernd

Am Do., 25. Apr. 2019 um 20:56 Uhr schrieb Adrian Böckenkamp <
notifications@github.com>:

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

CodeFinder2, 2019-04-26:
Thank you so much! :-)

I already removed the base plate successfully. I am just unable to get the PCB out of the plastic case. Also, the switch is still covered by some "(elastic) plastic cover" and I don't know how to get it out of it without destroying the PCB and/or plastic cover/case...

HerrPausL, 2019-04-26:
Hi Adrian,

the "trick" is: do not remove the base-plate (i made the same mistake) you
have to lift the black-cube from the silver-base
At http://bplagens.bplaced.net/ESP8266/ i have add a few pictures how i
managed it to open the enclosure.

Be carefull - on the inner-side of the black-cube are some clips - two
where broken :-(
But this is not a big point - it still fits!

[image: image.png]
When the black-cube is removed - you can remove very easy the pcb - it just
clipped into the base of the silver lower part.

BR Bernd

Am Fr., 26. Apr. 2019 um 12:53 Uhr schrieb Adrian Böckenkamp <
notifications@github.com>:

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

CodeFinder2, 2019-04-27:
Thank you very much! I successfully managed to open it. However, my ESP does not seem to enter flash mode even though I connected "GP0" to "GND". I am not even sure, if my PCB has an ESP8266 since it differs from yours (nevertheless, its label says "orvibo 0w8266-02z"):
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

Even worse and for whatever reason, I am not able to reset the device anymore (by pressing the "S1" button at the bottom until the red LED blinks quickly). When I power up the device, after some time, the blue LED (sometimes?) lights up shortly but then remains off (forever?). Nothing seems damaged and according to my multimeter, the device seems to have power (measured 5 and 3.3V at the appropriate pads respectively). I've also tried to connect via serial monitor (115200 bauds) but nothing is printed. Also, no Wifi hotspot is created (anymore) and it does not connect to my router anymore. (I used the HomeMate app to test the device once.)

Strange: the LEDs do not light up when I power it (either using the micro USB port or via serial 3.3V interface). :-/

Any ideas what I can try? Initially, I intended to backup the original firmware using *esptool* but this seems impossible now and obviously, I am even unable to flash this repo's firmware... :-(

CodeFinder2, 2019-05-27:
I managed to repair my board. And I can confirm that it actually has an ESP8266. ;-)

For others: please note that the pin header holes have a contact spacing of 2mm (not 2.54mm) so would need something like [this](https://www.aliexpress.com/item/20-Pcs-Per-Lot-2mm-Pitch-2x3-Pin-6-Pin-Female-Double-Row-Straight-Pin-Header/32499983748.html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,searchweb201602_10_10065_10068_10547_319_317_10548_10696_10084_453_10083_454_10618_10304_10307_10820_10821_537_10302_536_10843_10059_10884_10887_321_322_10103,searchweb201603_53,ppcSwitch_0&algo_expid=1bd82391-c717-451a-8a82-2050e03fa741-6&algo_pvid=1bd82391-c717-451a-8a82-2050e03fa741&transAbTest=ae803_3) (or its appropriate male counterpart).

cydia2020, 2020-06-20:
Thanks a lot for this, I did not know it was ESP8266 based.

mutantxxxx, 2020-11-25:
May I ask , I have flashed the standard tas build to Orvibo , but now want it to learn IR codes ,, a little unsure how to go about that .I use domoticz as the base home automation
Probably better to put tas ir build on unit .just learning codes

hkrob, 2020-11-27:
@mutantxxxx  I am about to follow the same path and install Tasmota.
I presume 'learning' is a process of sniffing IR commands, I found "Receiving IR Commands" on https://tasmota.github.io/docs/Tasmota-IR/ which looks promising.

Would you mind sharing how you flashed Tasmota on your magic cube?

> May I ask , I have flashed the standard tas build to Orvibo , but now want it to learn IR codes ,, a little unsure how to go about that .I use domoticz as the base home automation
> Probably better to put tas ir build on unit .just learning codes

cydia2020, 2020-11-27:
See IRReceived and IRSend. I think "Learning" is basically sending what you've received using the IRSend command

Malakai-DB, 2022-03-08:
@HerrPausL @CodeFinder2
I don't really manage to open the case (I already damaged it).
Should I try to lift the black-cube from the silver-base as shown in
1)
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
or
2)
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

If you have pictures of yours opened it will be most helpful (the link from this [post](https://github.com/mdhiggins/ESP8266-HTTP-IR-Blaster/issues/248#issuecomment-487078940) gives a 404 error).

cydia2020, 2022-03-09:
You should separate the black cube from the silver base, as shown in picture 1

HerrPausL, 2022-03-09:
Sorry,
i did not managed to find the pictures right now.
This pictures where made quickly - i hope it will help you:
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

At all 4 sides you will have 2 lugs which will snap into the cover (and a little bit of glue in the middle). The best way is to use a sharp knive.
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

Malakai-DB, 2022-03-09:
Thank you both for your input. I managed to open it and flash Tasmota and now the fun begins integrating it in Home Assistant.

HerrPausL, 2022-10-11:
Hello,
sorry for the broken link!
After work I will try to find the old pictures.
If I'm honest, I can't remember exactly where it was to open - so I'll have
to look at the pictures as well.

BR Bernd

Am Di., 8. März 2022 um 13:50 Uhr schrieb Malakai-DB <
***@***.***>:

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

thomsunrd, 2024-04-04:
> I managed to repair my board. And I can confirm that it actually has an ESP8266. ;-)
>
> For others: please note that the pin header holes have a contact spacing of 2mm (not 2.54mm) so would need something like [this](https://www.aliexpress.com/item/20-Pcs-Per-Lot-2mm-Pitch-2x3-Pin-6-Pin-Female-Double-Row-Straight-Pin-Header/32499983748.html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,searchweb201602_10_10065_10068_10547_319_317_10548_10696_10084_453_10083_454_10618_10304_10307_10820_10821_537_10302_536_10843_10059_10884_10887_321_322_10103,searchweb201603_53,ppcSwitch_0&algo_expid=1bd82391-c717-451a-8a82-2050e03fa741-6&algo_pvid=1bd82391-c717-451a-8a82-2050e03fa741&transAbTest=ae803_3) (or its appropriate male counterpart).

Hi @CodeFinder2 , how did you managed to repair the board, mine lits up with faint blue light. Any tips.

CodeFinder2, 2024-04-04:
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

Sorry, this is too long ago, I don't really remember and I am not using the device anymore. 😐

sledim, 2025-05-03:
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

Hi. Pls help flash this device for ir send and copy

sledim, 2025-05-03:
Usb, arduino?

Closed 2020-04-24.

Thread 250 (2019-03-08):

Use VU instead of VIN if board has VU

deftdawg, 2019-03-08:
I have a board with a VU pin on it, this pin provides ~5V while on this board VIN provides only ~1.7V.

Not sure the best way to mention this in the doc without creating confusion.  I spent about an hour wondering why I could emit with 3V and not VIN, then googled and discovered the problem was my variant of ESP8266 has a VU pin.

Hopefully this helps someone...

helloray, 2019-03-26:
I met the same issue.  I tested the VIN voltage and found it's only 1.7V.

Closed 2020-04-24.

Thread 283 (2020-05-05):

Silicon Labs website updated, USB to UART driver link no longer correct in README.md

PicoMitchell, 2020-05-05:
The new correct URL is: https://www.silabs.com/products/development-tools/software/usb-to-uart-bridge-vcp-drivers

mdhiggins, 2020-05-05:
Updated the readme, thanks

Closed 2020-05-05.

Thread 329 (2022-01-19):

Range of IR blaster

daknightuk, 2022-01-19:
So I followed this diagram exactly
100ohm resistor
2n2222 transistor
1k resistor
IR333-A

However the range of my IR blaster is about 3 metres. I need about 5m
I'm using the 5v Vin pin 30
am wondering if there is actually 5v

I've been able to use an IR LED between GND and GPI04 and it works with no transistor, resistor but still doesn't give the required range.

Any ideas on how I can get the range up?

David

mdhiggins, 2022-01-19:
5V should be the highest output, can check with a voltmeter if you're getting that, some knock off or v3 boards might not give you full 5V, not much you can do about that though other than get a different board

Otherwise, you have essentially 2 options to get more brightness
1. Get a different LED
2. Use a lower resistance

If you combine a bright LED that can handle more current, you should get more brightness

Connecting directly to GPIO4 will give you pretty low current and brightness, the whole reason for using the transistor and connecting to 5V is to push as much as possible
The 1k resistor won't affect brightness, that's just for the transistor to control the circuit

I use a 10-ohm resistor and these LEDs https://www.amazon.com/gp/product/B00ULB0U44/ which can handle higher bursts of current for short stints on some of my devices that need longer range

daknightuk, 2022-01-20:
Hi Michael,
I'm using a V2 board, https://www.az-delivery.uk/products/nodemcu
I couldn't get the same IR LED as you from anywhere so I looked on this website where the datasheet was and found out its actually an Everlight IR333-A https://cdn-shop.adafruit.com/datasheets/IR333_A_datasheet.pdf
After I messaged I found a circuit diagram which had a similar setup but no R1 1k ohms on the base of the transistor.
I tried it just to see what it would do and strangely I got brighter output and more range, not as much as I would like but I'm guessing that this will be down to the voltage as you say. I will have to get a voltmeter on Vin and see what its reading.
I'll try a 10ohm and see whether it makes it brighter

David

mdhiggins, 2022-01-20:
I wouldn't think the transistor resistor would make a difference (unless you maybe have it connected to the wrong leg of the transistor) but I'm no electrical engineer

mdhiggins, 2022-01-21:
I'm wrong

https://forum.arduino.cc/t/how-to-calculate-resistor-to-a-base-of-a-2n2222/206798/22

Decreasing both resistors is probably beneficial here

mdhiggins, 2022-01-21:
Looks like you should just max the current coming off the GPIO in addition to maybe lowering your LED resistor

12mA appears to be the max for the GPIO pins so adjust your resistor accordingly

daknightuk, 2022-01-24:
@mdhiggins So it appears that there are slight variations on the ESP8266, I have 2  circuits (one excluding all resistors) which works great has a long range and one which I had to add the resistors back in as it Popped the IR LED.
Must be a sign of poor manufacturing or quality control, I've ordered the LED you suggested and will use it with a 10 ohm resistor.

Closed 2022-01-19.

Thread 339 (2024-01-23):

IR from remote received but board won't transmit

warrenjb, 2024-01-23:
Got project loaded to my esp8266 nodemcu and setup with Amazon and router.  Can receive IR signals from TV remote but cannot see LED light up with phone camera on transmit request with Alexa.  Using [these](https://www.amazon.com/gp/product/B07W8W2LNS/ref=ppx_yo_dt_b_search_asin_title?ie=UTF8&psc=1) LEDs instead.  Perhaps I need a different resistor setup?  Appreciate any help.

c4coer, 2024-01-28:
hello everybody,
 for same me too.
i am check all it's ok.
only led on D2

mdhiggins, 2024-01-28:
Share the command you're sending

c4coer, 2024-01-28:
hello
here are the commands that I tested:
Hostname MSG
http://IRCONTROL.local:80/msg?code=C08:SYMPHONY:12
Local IP MSG
http://192.168.0.5:80/msg?code=C08:SYMPHONY:12
Hostname JSON
http://IRCONTROL.local:80/json?plain=[{data:'C08',type:'SYMPHONY',length:12}]

on the controller's web page the orders are indicated sent

thank's

mdhiggins, 2024-01-28:
Do non symphony style codes send? Have you tried modifying the PIN for your sender?

c4coer, 2024-01-28:
for exemple: http://192.168.0.5/json?plain=[{data:%27C08%27,type:%27SYMPHONY%27,length:12,out:4}]
i tested 1 to 4 it's no ok

c4coer, 2024-01-28:
I tried on two D1 mini cards and I use an esp8266 nodemcu V3 because it is more practical, but the problem is the same on both, I do not see any command on the output to drive the transistor

mdhiggins, 2024-01-28:
What's the serial output when you try these commands?

c4coer, 2024-01-28:
I tried D2 and D6

mdhiggins, 2024-01-28:
That does answer the question

And is it any different if you do a non symphony command. Do like a basic SONY or NEC command and see

mdhiggins, 2024-01-28:
Please post the serial output when trying to send these commands

c4coer, 2024-01-28:
actually I tried a sony code and the IR is on.

http://192.168.0.5/msg?code=540C:SONY:15.

so that means that the library, I don't manage my codes?

c4coer, 2024-01-28:
thanks you for your help.

warrenjb, 2024-01-29:
Interesting that the wrong code breaks the device.  Here is my code:
http://externalip:80/msg?code=40040100BCBD:PANASONIC:48&address=0x4004&pass=mypassword
Does this look wrong?

mdhiggins, 2024-01-29:
The air conditioner protocols are often massive and exceed the memory limit of the ESP8266, hence why I was asking about the serial output

The panasonic code looks fine

warrenjb, 2024-01-29:
Any idea why led it not lighting up?  The calls are registering in the cloud.  Also your write up calls for 10 and 1000 resistors but your schematic calls for 100 and 1000.  I assumed the sketch was right?

mdhiggins, 2024-01-29:
Nope post the serial output while you're trying to send a code

And the resistors have quite a bit of flexibility and will vary depending on what LED you've chosen

warrenjb, 2024-01-29:
Serial output:
11:39:04.245 -> Turning off the LED to save power.
11:39:09.570 -> Connection received endpoint '/msg'
11:39:09.570 -> Client IP: X.X.X.X
11:39:09.570 -> Client IP: X.X.X.X
11:39:09.570 -> Passed security check
11:39:09.570 -> MID: 6d6a458e-94ed-4e2a-a5e0-ade3d5bafccf
11:39:09.570 -> Blasting off
11:39:09.570 -> Blocking incoming IR signals
11:39:09.570 -> 40040100BCBD:panasonic:48
11:39:09.616 -> Address: 16388
11:39:09.756 -> Transmission complete
11:39:09.756 -> Reenabling receiving
11:39:10.083 -> Turning off the LED to save power.

mdhiggins, 2024-01-29:
Alright so doesn't look like a software issue.

Might need to post some pics of your hardware. Also lots of cameras have IR filters so make sure that's not giving you a false negative.

warrenjb, 2024-01-29:
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

Pointed remote at phone and saw blast so not a filter on phone issue.

mdhiggins, 2024-02-01:
Looks appropriately wired from what I can tell

Things to try
- use the MQTT-dev branch of the script, this is much newer the main branch is old, it does not have to be used specifically for MQTT; this words best with platformio, default settings should be fine as mqtt is opt-in
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
- eliminate the resistors (not a good long term option but for testing purposes you can at least see)
- test your LED with a simple blueprint to ensure the LED is good (can probably find these anywhere, like https://docs.arduino.cc/built-in-examples/basics/Blink/)
- try a simple command without an address (use `A90:SONY:12`)

c4coer, 2024-02-06:
hello
my assembly works well with two LEDs in series. I doubled the reception cache, and I used AI to optimize RAW codes that were too long. thanks you

Closed 2024-03-14.

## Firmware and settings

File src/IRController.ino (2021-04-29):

#include <FS.h>                                               // This needs to be first, or it all crashes and burns

#include <IRremoteESP8266.h>
#include <IRsend.h>
#include <IRrecv.h>
#include <IRutils.h>
#include <ESP8266WiFi.h>
#include <WiFiManager.h>                                      // https://github.com/tzapu/WiFiManager WiFi Configuration Magic
#include <ESP8266mDNS.h>                                      // Useful to access to ESP by hostname.local

#include <ArduinoJson.h>
#include <ESP8266WebServer.h>
#include <ESP8266HTTPClient.h>
#include <ArduinoOTA.h>
#include "sha256.h"

#include <Ticker.h>                                           // For LED status
#include <TimeLib.h>

#include <LittleFS.h>

// User settings are below here
//+=============================================================================
const bool getExternalIP = true;                               // Set to false to disable querying external IP

const bool getTime = true;                                     // Set to false to disable querying for the time
const int timeZone = -5;                                       // Timezone (-5 is EST)

const bool enableMDNSServices = true;                          // Use mDNS services, must be enabled for ArduinoOTA

const bool bypassLocalAuth = true;                             // Allow local traffic to bypass HMAC check

const unsigned int captureBufSize = 1024;                      // Size of the IR capture buffer.

const bool toggleRC = true;                                    // Toggle RC signals every other transmission

#if defined(ARDUINO_ESP8266_WEMOS_D1R1) || defined(ARDUINO_ESP8266_WEMOS_D1MINI) || defined(ARDUINO_ESP8266_WEMOS_D1MINIPRO) || defined(ARDUINO_ESP8266_WEMOS_D1MINILITE)
const uint16_t  pinr1 = D5;                                          // Receiving pin (GPIO14)
const uint16_t  pins1 = D6;                                          // Transmitting preset 1 (GPIO12)
const uint16_t  configpin = D2;                                      // Reset Pin (GPIO4)
const uint16_t  pins2 = 5;                                           // Transmitting preset 2
const uint16_t  pins3 = 12;                                          // Transmitting preset 3
const uint16_t  pins4 = 13;                                          // Transmitting preset 4
#else
const uint16_t  pinr1 = 14;                                          // Receiving pin
const uint16_t  pins1 = 4;                                           // Transmitting preset 1
const uint16_t  configpin = 10;                                      // Reset Pin
const uint16_t  pins2 = 5;                                           // Transmitting preset 2
const uint16_t  pins3 = 12;                                          // Transmitting preset 3
const uint16_t  pins4 = 13;                                          // Transmitting preset 4
#endif
//+=============================================================================
// User settings are above here

const int ledpin = LED_BUILTIN;                                // Built in LED defined for WEMOS people
const char *wifi_config_name = "IR Controller Configuration";
const char serverName[] = "checkip.dyndns.org";
int port = 80;
char passcode[20] = "";
char host_name[20] = "";
char port_str[6] = "80";
char user_id[60] = "";

// Do not modify these values with your own, they are placeholder values that WiFiManager will overwrite
char static_ip[16] = "10.0.1.10";
char static_gw[16] = "10.0.1.1";
char static_sn[16] = "255.255.255.0";
char static_dns[16] = "10.0.1.1";

DynamicJsonDocument deviceState(1024);

WiFiClient client;
ESP8266WebServer *server = NULL;
Ticker ticker;

bool shouldSaveConfig = false;                                 // Flag for saving data
bool holdReceive = false;                                      // Flag to prevent IR receiving while transmitting

IRrecv irrecv(pinr1, captureBufSize, 35);
IRsend irsend1(pins1);
IRsend irsend2(pins2);
IRsend irsend3(pins3);
IRsend irsend4(pins4);

const unsigned long resetfrequency = 259200000;                // 72 hours in milliseconds for external IP reset
static const char ntpServerName[] = "time.google.com";
unsigned int localPort = 8888;                                 // Local port to listen for UDP packets
void sendNTPpacket(IPAddress &address);
time_t getNtpTime();
WiFiUDP ntpUDP;

bool _rc5toggle = false;
bool _rc6toggle = false;

char _ip[16] = "";

unsigned long lastupdate = 0;

bool authError = false;
time_t timeAuthError = 0;
bool externalIPError = false;
bool userIDError = false;
bool ntpError = false;

class Code {
  public:
    char encoding[14] = "";
    char address[20] = "";
    char command[40] = "";
    char data[40] = "";
    String raw = "";
    int bits = 0;
    time_t timestamp = 0;
    bool valid = false;
};

// Declare prototypes
void sendCodePage(Code selCode);
void sendCodePage(Code selCode, int httpcode);
void cvrtCode(Code& codeData, decode_results *results);
void copyCode (Code& c1, Code& c2);

Code last_recv;
Code last_recv_2;
Code last_recv_3;
Code last_recv_4;
Code last_recv_5;
Code last_send;
Code last_send_2;
Code last_send_3;
Code last_send_4;
Code last_send_5;

//+=============================================================================
// Callback notifying us of the need to save config
//
void saveConfigCallback () {
  Serial.println("Should save config");
  shouldSaveConfig = true;
}


//+=============================================================================
// Reenable IR receiving
//
void resetReceive() {
  if (holdReceive) {
    Serial.println("Reenabling receiving");
    irrecv.resume();
    holdReceive = false;
  }
}


//+=============================================================================
// Valid user_id formatting
//
bool validUID(char* user_id) {
  if (!String(user_id).startsWith("amzn1.account.")) {
      Serial.println("Warning, user_id appears to be in the wrong format, security check will most likely fail. Should start with amzn1.account.***");
      return false;
    }
    return true;
}


//+=============================================================================
// Valid EPOCH time retrieval
//
bool validEPOCH(time_t timenow) {
  if (timenow < 922838400) {
    Serial.println("Epoch time from timeServer is unexpectedly old, probably failed connection to the time server. Check your network settings");
    Serial.println(timenow);
    return false;
  }
  return true;
}


//+=============================================================================
// EPOCH time to String
//
String epochToString(time_t timenow) {
  unsigned long hours = (timenow % 86400L) / 3600;
  String hourStr = hours < 10 ? "0" + String(hours) : String(hours);

  unsigned long minutes = (timenow % 3600) / 60;
  String minuteStr = minutes < 10 ? "0" + String(minutes) : String(minutes);

  unsigned long seconds = (timenow % 60);
  String secondStr = seconds < 10 ? "0" + String(seconds) : String(seconds);
  return hourStr + ":" + minuteStr + ":" + secondStr;
}

//+=============================================================================
// Valid command request using HMAC
//
bool validateHMAC(String epid, String mid, String timestamp, String signature, IPAddress clientIP) {
    userIDError = false;
    authError = false;
    ntpError = false;
    timeAuthError = 0;

    if (allowLocalBypass(clientIP)) {
      Serial.println("Bypassing HMAC security as this is a local network request");
      return true;
    }

    userIDError = !(validUID(user_id));

    time_t timethen = timestamp.toInt();
    time_t timenow = now() - (timeZone * SECS_PER_HOUR);
    time_t timediff = abs(timethen - timenow);
    if (timediff > 30) {
      Serial.println("Failed security check, signature is too old");
      Serial.print("Server: ");
      Serial.println(timethen);
      Serial.print("Local: ");
      Serial.println(timenow);
      Serial.print("MID: ");
      Serial.println(mid);
      timeAuthError = timediff;
      validEPOCH(timenow);
      return false;
    }

    uint8_t *hash;
    String key = String(user_id);
    Sha256.initHmac((uint8_t*)key.c_str(), key.length()); // key, and length of key in bytes
    Sha256.print(epid);
    Sha256.print(mid);
    Sha256.print(timestamp);
    hash = Sha256.resultHmac();
    String computedSignature = bin2hex(hash, HASH_LENGTH);

    if (computedSignature != signature) {
      Serial.println("Failed security check, signatures do not match");
      Serial.print("1: ");
      Serial.println(signature);
      Serial.print("2: ");
      Serial.println(computedSignature);
      Serial.print("MID: ");
      Serial.println(mid);
      authError = true;
      return false;
    }

    Serial.println("Passed security check");
    Serial.print("MID: ");
    Serial.println(mid);
    return true;
}

//+=============================================================================
// Check if client request is coming from a local IP address
//
bool isInSubnet(IPAddress address) {
    Serial.print("Client IP: ");
    Serial.println(address.toString());

    uint32_t mask = uint32_t(WiFi.subnetMask());

    /*
    uint32_t net_lower = (uint32_t(WiFi.localIP()) & mask);
    uint32_t net_upper = (net_lower | (~mask));
    Serial.println(IPAddress(net_lower).toString());
    Serial.println(IPAddress(net_upper).toString());
    */

    return ((uint32_t(address) & mask) == (uint32_t(WiFi.localIP()) & mask));
}

//+=============================================================================
// Allow local traffic to bypass security
//
bool allowLocalBypass(IPAddress clientIP) {
  return (bypassLocalAuth && isInSubnet(clientIP));
}

//+=============================================================================
// Passcode valid check
//
bool isPasscodeValid(String pass) {
  return ((strlen(passcode) == 0) || (pass == passcode));
}

//+=============================================================================
// Get User_ID from Amazon Token (memory intensive and causes crashing)
//
String getUserID(String token)
{
  HTTPClient http;
  http.setTimeout(5000);
  String url = "https://api.amazon.com/user/profile?access_token=";
  String uid = "";
  http.begin(client, url + token);
  int httpCode = http.GET();
  String payload = http.getString();
  Serial.println(url + token);
  Serial.println(httpCode);
  Serial.println(payload);
  if (httpCode > 0 && httpCode == HTTP_CODE_OK) {
    DynamicJsonDocument json(1024);
    deserializeJson(json, payload);
    uid = json["user_id"].as<String>();
  } else {
    Serial.println("Error retrieving user_id");
    payload = "";
  }
  http.end();
  return uid;
}


//+=============================================================================
// Toggle state
//
void tick()
{
  int state = digitalRead(ledpin);  // get the current state of GPIO1 pin
  digitalWrite(ledpin, !state);     // set pin to the opposite state
}


//+=============================================================================
// Get External IP Address
//
String externalIP()
{
  if (!getExternalIP) {
    return "0.0.0.0"; // User doesn't want the external IP
  }

  if (strlen(_ip) > 0) {
    unsigned long delta = millis() - lastupdate;
    if (delta > resetfrequency || lastupdate == 0) {
      Serial.println("Reseting cached external IP address");
      strncpy(_ip, "", 16); // Reset the cached external IP every 72 hours
    } else {
      return String(_ip); // Return the cached external IP
    }
  }

  HTTPClient http;
  externalIPError = false;
  unsigned long start = millis();
  http.setTimeout(5000);
  http.begin(client, serverName, 8245);
  int httpCode = http.GET();

  if (httpCode > 0 && httpCode == HTTP_CODE_OK) {
    String payload = http.getString();
    int pos_start = payload.indexOf("IP Address") + 12; // add 10 for "IP Address" and 2 for ":" + "space"
    int pos_end = payload.indexOf("</body>", pos_start); // add nothing
    strncpy(_ip, payload.substring(pos_start, pos_end).c_str(), 16);
    Serial.print(F("External IP: "));
    Serial.println(_ip);
    lastupdate = millis();
  } else {
    Serial.println("Error retrieving external IP");
    Serial.print("HTTP Code: ");
    Serial.println(httpCode);
    Serial.println(http.errorToString(httpCode));
    externalIPError = true;
  }

  http.end();
  Serial.print("External IP address request took ");
  Serial.print(millis() - start);
  Serial.println(" ms");

  return _ip;
}


//+=============================================================================
// Turn off the Led after timeout
//
void disableLed()
{
  Serial.println("Turning off the LED to save power.");
  digitalWrite(ledpin, HIGH);                           // Shut down the LED
  ticker.detach();                                      // Stopping the ticker
}


//+=============================================================================
// Gets called when WiFiManager enters configuration mode
//
void configModeCallback (WiFiManager *myWiFiManager) {
  Serial.println("Entered config mode");
  Serial.println(WiFi.softAPIP());
  //if you used auto generated SSID, print it
  Serial.println(myWiFiManager->getConfigPortalSSID());
  //entered config mode, make led toggle faster
  ticker.attach(0.2, tick);
}


//+=============================================================================
// Gets called when device loses connection to the accesspoint
//
void lostWifiCallback (const WiFiEventStationModeDisconnected& evt) {
  Serial.println("Lost Wifi");
  // reset and try again, or maybe put it to deep sleep
  ESP.reset();
  delay(1000);
}


//+=============================================================================
// First setup of the Wifi.
// If return true, the Wifi is well connected.
// Should not return false if Wifi cannot be connected, it will loop
//
bool setupWifi(bool resetConf) {
  // start ticker with 0.5 because we start in AP mode and try to connect
  ticker.attach(0.5, tick);
  
  WiFi.mode(WIFI_STA); // To make sure STA mode is preserved by WiFiManager and resets it after config is done.
  
  // WiFiManager
  // Local intialization. Once its business is done, there is no need to keep it around
  WiFiManager wifiManager;

  // set callback that gets called when connecting to previous WiFi fails, and enters Access Point mode
  wifiManager.setAPCallback(configModeCallback);
  // set config save notify callback
  wifiManager.setSaveConfigCallback(saveConfigCallback);

  // Reset device if on config portal for greater than 3 minutes
  wifiManager.setConfigPortalTimeout(180);

  if (LittleFS.begin()) {
    Serial.println("mounted file system");
    if (LittleFS.exists("/config.json")) {
      //file exists, reading and loading
      Serial.println("reading config file");
      File configFile = LittleFS.open("/config.json", "r");
      if (configFile) {
        Serial.println("opened config file");
        size_t size = configFile.size();
        // Allocate a buffer to store contents of the file.
        std::unique_ptr<char[]> buf(new char[size]);

        configFile.readBytes(buf.get(), size);
        DynamicJsonDocument json(1024);
        DeserializationError error = deserializeJson(json, buf.get());
        serializeJson(json, Serial);
        if (!error) {
          Serial.println("\nparsed json");

          if (json.containsKey("hostname")) strncpy(host_name, json["hostname"], 20);
          if (json.containsKey("passcode")) strncpy(passcode, json["passcode"], 20);
          if (json.containsKey("user_id")) strncpy(user_id, json["user_id"], 60);
          if (json.containsKey("port_str")) {
            strncpy(port_str, json["port_str"], 6);
            port = atoi(json["port_str"]);
          }
          if (json.containsKey("ip")) strncpy(static_ip, json["ip"], 16);
          if (json.containsKey("gw")) strncpy(static_gw, json["gw"], 16);
          if (json.containsKey("sn")) strncpy(static_sn, json["sn"], 16);
          if (json.containsKey("dns")) strncpy(static_dns, json["dns"], 16);
        } else {
          Serial.println("failed to load json config");
        }
      }
    }
  } else {
    Serial.println("failed to mount FS");
  }

  WiFiManagerParameter custom_hostname("hostname", "Choose a hostname to this IR Controller", host_name, 20);
  wifiManager.addParameter(&custom_hostname);
  WiFiManagerParameter custom_passcode("passcode", "Choose a passcode", passcode, 20);
  wifiManager.addParameter(&custom_passcode);
  WiFiManagerParameter custom_port("port_str", "Choose a port", port_str, 6);
  wifiManager.addParameter(&custom_port);
  WiFiManagerParameter custom_userid("user_id", "Enter your Amazon user_id", user_id, 60);
  wifiManager.addParameter(&custom_userid);

  wifiManager.setShowStaticFields(true);
  wifiManager.setShowDnsFields(true);

  IPAddress sip, sgw, ssn, dns;
  sip.fromString(static_ip);
  sgw.fromString(static_gw);
  ssn.fromString(static_sn);
  dns.fromString(static_dns);

  if (resetConf) {
    Serial.println("Reset triggered, launching in AP mode");
    wifiManager.startConfigPortal(wifi_config_name);
  } else {
    Serial.println("Setting static WiFi data from config");
    wifiManager.setSTAStaticIPConfig(sip, sgw, ssn, dns);
  }

  // fetches ssid and pass and tries to connect
  // if it does not connect it starts an access point with the specified name
  // and goes into a blocking loop awaiting configuration
  if (!wifiManager.autoConnect(wifi_config_name)) {
    Serial.println("Failed to connect and hit timeout");
    // reset and try again, or maybe put it to deep sleep
    ESP.reset();
    delay(1000);
  }

  // if you get here you have connected to the WiFi
  strncpy(host_name, custom_hostname.getValue(), 20);
  strncpy(passcode, custom_passcode.getValue(), 20);
  strncpy(port_str, custom_port.getValue(), 6);
  strncpy(user_id, custom_userid.getValue(), 60);
  port = atoi(port_str);

  if (server != NULL) {
    delete server;
  }
  server = new ESP8266WebServer(port);

  // Reset device if lost wifi Connection
  WiFi.onStationModeDisconnected(&lostWifiCallback);

  Serial.println("WiFi connected! User chose hostname '" + String(host_name) + String("' passcode '") + String(passcode) + "' and port '" + String(port_str) + "'");

  // Save the custom parameters to FS
  if (shouldSaveConfig) {
    Serial.println(" config...");
    DynamicJsonDocument json(1024);
    json["hostname"] = host_name;
    json["passcode"] = passcode;
    json["port_str"] = port_str;
    json["user_id"] = user_id;
    json["ip"] = WiFi.localIP().toString();
    json["gw"] = WiFi.gatewayIP().toString();
    json["sn"] = WiFi.subnetMask().toString();
    json["dns"] = WiFi.dnsIP().toString();

    File configFile = LittleFS.open("/config.json", "w");
    if (!configFile) {
      Serial.println("failed to open config file for writing");
    }

    serializeJson(json, Serial);
    Serial.println("");
    Serial.println("Writing config file");
    serializeJson(json, configFile);
    configFile.close();
    json.clear();
    Serial.println("Config written successfully");
  }
  ticker.detach();

  // keep LED on
  digitalWrite(ledpin, LOW);
  return true;
}


//+=============================================================================
// Send CORS HTTP headers
//
void sendCorsHeaders() {
  server->sendHeader("Access-Control-Allow-Origin", "*");
  server->sendHeader("Access-Control-Allow-Methods", "GET, POST");
}
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
void loop() {
  ArduinoOTA.handle();
  server->handleClient();
  decode_results  results;                                        // Somewhere to store the results

  if (irrecv.decode(&results) && !holdReceive) {                  // Grab an IR code
    Serial.println("Signal received:");
    fullCode(&results);                                           // Print the singleline value
    dumpCode(&results);                                           // Output the results as source code
    copyCode(last_recv_4, last_recv_5);                           // Pass
    copyCode(last_recv_3, last_recv_4);                           // Pass
    copyCode(last_recv_2, last_recv_3);                           // Pass
    copyCode(last_recv, last_recv_2);                             // Pass
    cvrtCode(last_recv, &results);                                // Store the results
    last_recv.timestamp = now();                                  // Set the new update time
    last_recv.valid = true;
    Serial.println("");                                           // Blank line between entries
    irrecv.resume();                                              // Prepare for the next value
    digitalWrite(ledpin, LOW);                                    // Turn on the LED for 0.5 seconds
    ticker.attach(0.5, disableLed);
  }
  delay(200);
}

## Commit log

2017-01-11 version 2 initial commit
    Removed basic language
    Included new arduino blueprint
    Readme update to follow
2017-01-11 sample update
2017-01-14 support for using multiple IR leds
    readme update to follow
2017-01-14 multiple LED readme update
    cleaned parameter descriptions
    added out parameter documentation
    added small section explaining usage scenario
2017-01-19 rc5/rc6 fix
    did the other one too quickly
    [IRController.ino]
2017-01-19 roku control
    added the ability to command local roku devices using the API
    technically not IR related but I needed it
2017-01-21 http variable error fix
    [IRController.ino]
2017-03-14 Software enhancements
    - let user configure wifi on first boot. no more
    need to hardcode the passwords
    - user can set the name of the blaster. Will be
    accessible on the local network through
    <name given by user>.local
    - bonjour service added
    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
2017-03-17 Less power consumption
    Adding delay in the loop seems to help
    decreasing the power consumption.
    It does not impact the reaction time,
    around 6s for each command.
    Of course, rush of commands might be
    impacted
2017-05-12 support port configuration
    Port can now be configured via WiFi manager’s options, no need to edit
    the blueprint
2017-05-13 fixes
    whitespace clean up
    [IRController.ino]
2017-06-18 IRremoteESP8266 2.0 compatibility update
    Included changes required to make compatible with version 2.0 of the IR
    library
    Adjusted default GPIO send ports since 13 is the reset port now and 0
    prevents the device from booting if connected (flash)
    [IRController.ino]
2017-06-18 SONY readme update
    New IR library doesn’t require SONY codes to be pulsed
2017-06-19 web updates
    now outputs server info to the root URL
    new /last page that shows the last signal received. No longer need to
    use serial monitoring to grab codes
    [IRController.ino]
2017-06-19 mac address handling
    Cleaner and faster mac address printing
2017-06-29 IP and last print updates
    Include the external IP address in the info page
    Updates to the formatting of the /last page
2017-06-30 cosmetic patch
    increase stored codes to 5
    store sent codes as well
    new page to display the codes
    refer to new page for code sent/error pages
    new code summary page with example URLs and data
    Blink the light when a code is received
    cleaned up old code for old html pages
    [IRController.ino]
2017-06-30 trigger check if millis() has looped
2017-06-30 more fixes
    LED pin fix for wemo
    Crash fix when trying to enter URL that doesn’t have a code yet
    HTML tag cleanup
    Using <code> consistently
    Home link
    RAW code copy fix
    Added some green coloring cause green is the best
    Blink after sending a code
    [IRController.ino]
2017-06-30 typo fix
    spelled plain correctly
    [IRController.ino]
2017-06-30 html validation
    improved compliance with bootstraps protocol
    html validated and passing without errors
    UI inconsistencies fixed
    [IRController.ino]
2017-07-01 prevent receiving own codes
    Prevent receiving codes transmitted by self
    [IRController.ino]
2017-07-01 additional fixes
    whitespace cleanup
    mobile scaling to 0.75
    badge adjustment
    [IRController.ino]
2017-07-01 allow disabling of externalIP query and NTP
    Reduces latency on systems with slow internet connection
    Added NTP re-sync every 72 hours
    Query external IP on boot
    Serial output for external IP query time
    Added a ‘!’ to header message
2017-07-02 html streaming model
    moved to an HTML streaming model instead of dumping everything into a
    string which could produce errors and memory leaks, much more efficient
    this way
    added line breaks to the html as well
    [IRController.ino]
2017-07-02 HTML cleanup
    Fixed spacing for HTML so tabs are appropriate when viewing source
    Also added a “no codes sent/received” when no values are present for
    the table
    [IRController.ino]
2017-07-02 more fixes
    removed auto refresh
    spacing fix
    link to github
    [IRController.ino]
2017-07-03 port_str and json
    adjustments made to port_str and size reduced
    son checks to ensure json can be read without crashing
    [IRController.ino]
2017-07-06 schematic fix
2017-07-08 adjust default pins
    Better for nodemcu compliance
    Additionally putting the receiver on GPIO14 lets the receiver be placed
    without additional wires
    Moved the LED flash when a command is received to the beginning
2017-07-23 raw fixes
    Fixed error when negative numbers were in the raw data using unsigned
    int would cause prolonged hang as they would be converted to very large
    positive numbers
    Added raw transmits to the list of codes being sent
    Added conditionals to clear data for codes that are missing certain
    elements
    [IRController.ino]
2017-08-09 reset pin to 15
    prevent conflicting reset and irsend4
    [IRController.ino]
2017-09-13 update for latest IRLibrary
    Replaces USECPERTICK with RAWTICK
    [IRController.ino]
2017-09-28 improvements
    Efficiency improvements with simple response time; useful for in
    development accompanying Alexa skill
    Change reset pin to GPIO10 since 15 was variable and sometimes
    defaulted to LOW causing endless setting resets
    Added serial output to indicate reset pin state for debugging purposes
    [IRController.ino]
2017-10-01 typo fix
    removed sanyo which apparently isn’t in the library
    [IRController.ino]
2017-10-01 print local
2017-10-05 remember device state
2017-11-14 security update
    memory improvements (switched from jsonBuffer and dynamic objects to
    custom class for storing prior sent/received codes)
    sha256 emac security authentication with Alexa
    function that can verify user_id with token (not in use)
    helper functions
    code cleanup for deprecated functions
2017-11-15 static IP
    Change from DHCP to static. Makes way more sense for this device since
    ports need to be forwarded
2017-11-17 improve security failure error logging
    [IRController.ino]
2017-11-19 bad user_id feedback
    Updated the readme to further clarify the user_id format and put a
    console log error in place to try to alert people when they still did
    it wrong
    [IRController.ino]
2017-11-19 same fix for raw blast
    [IRController.ino]
2017-11-20 passcode adjustment
    do not fail passcode auth if one is in the url but no passcode is
    required
    [IRController.ino]
2017-12-18 Improve "IR code too long" warning formatting
    [IRController.ino]
2017-12-18 Fix UNKNOWN url display
    [IRController.ino]
2018-01-08 mdns options
    added bool to enable/disable mins services
    consolidated arduinoOTA and mdns configurations since they were
    redundant and may have been conflicting
2018-01-13 configpin 10
    Fixed back to default setting
    [IRController.ino]
2018-01-14 Fix repeat indicator in decode results string
    [IRController.ino]
2018-01-15 Parse irblast code data to uint64_t
    That's what current IRsend expects, and some implementations require
    more data than what fits in unsigned long.
2018-01-16 better epoch error reporting
    [IRController.ino]
2018-01-17 Update IRController.ino
    Fix strtoull -->strtoul in line 1304
    [IRController.ino]
2018-01-17 Revert "Merge pull request #133 from zobotek/master"
    This reverts commit aebe57a1bdfb573436c1a1e59058e4c6c1766043, reversing
    changes made to cc4f9995c1dbf44adae11c93666d7161eeeea1bd.
    [IRController.ino]
2018-01-17 remove attempted lwip2.0 fix
    Officially not supporting lwIP until the bugs are worked out
    1.4 for now
    [IRController.ino]
2018-02-13 NTP library change
    Switch to EasyNTPClient
    Having recurrent issues with epoch desyncing with NTPClient causing
    authentication errors
    Not sure why and unable to stabilize, EasyNTPClient seems to not share
    these issues
    [IRController.ino]
2018-03-25 show browser epoch time
    For comparison
    Still occasionally (though rarely) getting failures due to NTP syncing
    problems
    [IRController.ino]
2018-08-28 change ntp client
    also declare prototypes
    Had issue where script suddently wouldn't compile with a new computer, delcaring prototypes seems to fix
    add images used by Alexa skill icons
    [IRController.ino]
2018-09-25 Update to facilitate change to IRremoteESP8266 2.5
    As per the IRremoteESP8266 v.2.5, the following changes have been made:
    "The library has changed from using constants declared as #define to const with the appropriate naming per the C++ style guide. This may potentially cause old programs to not compile. The most likely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
    In the unlikely case it does break your code, then you may have been referencing something you likely should not have. You should be able to quickly determine the ne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
2018-10-11 Use the 2.4.0 Arduino library
2018-10-11 switch to correct board/version
2018-10-23 new time library
    ntpClient was having too many problems and not reliable, gonna try Time
    [IRController.ino]
2019-05-30 Migrate ArduinoJson from version 5 to 6
2019-06-01 Use library names instead of IDs, fix versions (code is incompatible with ArduinoJson v6)
2019-06-01 Use LED_BUILTIN instead of depricated BUILTIN_LED
2019-06-01 fix compile warning (comparing signed to unsigned int)
    [IRController.ino]
2019-11-06 development fork
    tested using latest versions of arduinojson, wifimanager (dev branch), esp8266 core, and irremote
    can now have dynamic or static IP configuration options and can manually set DNS address which fixes lots of issues
    works with lwIP 2.0
    [IRController.ino]
2019-11-06 null fix
    fixes device state issue with arduinojson 6
    [IRController.ino]
2019-11-06 fix device state
    fix null devices for arduinojson 6
    [IRController.ino]
2019-11-06 dns improvements
    further dns improvements using new wifiManager options
    cache and assign static values except when using configuration AP mode
    Added dns to the web interface and connection print out
2019-11-07 error reporting
    include a message in comments to alert lolin v3 people
    Removed the 2.4.0 warning since that's now been resolved
    [IRController.ino]
2020-04-25 expand raw memory and include json parsing error
    [IRController.ino]
2020-05-05 fix driver link
2020-12-26 use typeToString
    replace outdated method
    [IRController.ino]
2021-02-15 Set WiFi.mode(WIFI_STA) before WiFiManager
    Fix for issue: https://github.com/mdhiggins/ESP8266-HTTP-IR-Blaster/issues/307
    [IRController.ino]
2021-03-14 additional board environments for platform IO
    nodemcuv2
    d1_mini
    d1_mini_lite
    d1_mini_pro
2021-03-14 Update IRController.ino
    remove SPIFFS references in favor of LittleFS
    fix spacing on comments
    new custom pin definition for the WEMOS variants
    [IRController.ino]
2021-03-15 Update IRController.ino
    don't process json body until security check has passed
    only send very simple failure message when security check fails instead of whole homepage
    require security for homepage and received page as well (since local bypass now exists)
    [IRController.ino]
